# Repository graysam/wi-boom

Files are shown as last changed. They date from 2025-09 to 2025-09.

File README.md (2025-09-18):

# HV Trigger Async (ESP32 / ESP32-S3)

Firmware for ESP32 boards hosting a minimal web UI to safely arm and trigger a high‑voltage initiator. AsyncTCP + ESPAsyncWebServer power a WebSocket control channel; configuration persists via Preferences.

## Features
- SoftAP: `Trigger-Remote` / `lollipop`, IP `10.11.12.1`.
- Inline UI from PROGMEM; no filesystem required.
- WebSocket at `/ws` for telemetry (~250 ms) and commands.
- Pulse controls: mode `single` or `buzz`, width, spacing, repeat.
- Hardware LEDs: amber/green (network/WS), red (armed), blue (pulse).
- Status bar: WS and Armed LEDs, mode label (BUZZ/SINGLE‑SHOT), compact `W/S/R` values (e.g., `31/38/3`), AP name; reconnect overlay while WS is down.
- OTA via ArduinoOTA (TCP/3232) — update while the app is running.
- Verbose Serial logs for boot, prefs, HTTP, WS, and actions.

## Quickstart
1. Dependencies: ESP32 core (recommended 2.0.14), libraries in `library-notes.txt`.
2. Build & Burn scripts (recommended):
   - Windows: `buildAndBurn.ps1` (or `buildAndBurn.bat` wrapper)
   - macOS/Linux: `chmod +x buildAndBurn.sh && ./buildAndBurn.sh`
   Scripts prompt for sketch, FQBN, clean, port selection, upload, and can open a serial monitor.
3. Manual (Arduino IDE):
   - ESP32 Dev Module (ESP32‑WROOM‑32): select Board "ESP32 Dev Module".
   - ESP32‑S3 Dev Module: select Board "ESP32S3 Dev Module" and enable USB CDC on boot.
   Then open `hv_trigger_async.ino` and Upload.
4. Connect to AP `Trigger-Remote` and open `http://10.11.12.1/`.
5. OTA Update (optional):
   - Ensure your PC and the device are on the same network (AP or STA).
   - Arduino IDE: use the Network Port entry if available.
   - Arduino CLI: `arduino-cli upload -p 10.11.12.1:3232 --fqbn esp32:esp32:esp32 hv_trigger_async.ino` (replace FQBN for ESP32‑S3).

## Controls & Ranges
- Mode: `single` or `buzz`.
- Width: 5–100 ms; Spacing: 10–100 ms; Repeat: 1–4.
- Arm/Disarm gates firing; cfg changes are ignored while armed.

## Build & Tools
- Scripts: see above. CLI fallback in `README.build.md`.
- Serial monitor: `arduino-cli monitor -p COMX -c baudrate=115200`.
- WebSocket test (PowerShell): `powershell -ExecutionPolicy Bypass -File tools\\test_ws.ps1`

## API Reference
See `docs/WS_API.md` for WebSocket message formats, examples, and flows.

## Code Map
- `hv_trigger_async.ino`: setup/loop, telemetry tick, indicators.
- `web_server.cpp/.h`: AP setup, async server, WebSocket, inline UI, actions.
- `config.h`: pins, SoftAP settings, defaults; edit pins here if needed.

## Hardware
- KiCad project resides in `hardware_kicad/` (schematics `*.kicad_sch`, board `*.kicad_pcb`).
- Generated artifacts (plots, fabrication outputs, iBOM) are currently included from prototyping; going forward we’ll prefer attaching these to GitHub releases rather than committing bulk outputs.
- For fabrication, open in KiCad 7/8 and regenerate plots/GERBER/Drill files as needed. Additional notes may be present in `hardware_kicad/`.

## Safety
Change the default SoftAP password before field use. Treat the trigger output as live hardware — validate with a dummy load first.

## Release v1.21a
- Prototype hardware integrated and tested with the firmware.
- Repo/docs tidy-up; encoding fixes and clearer setup notes.
- Tag: `v1.21a` marks the working prototype snapshot.

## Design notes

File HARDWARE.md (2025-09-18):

# Hardware (KiCad)

## Overview
- Project directory: `hardware_kicad/`
- Core sources: schematics (`*.kicad_sch`), board (`*.kicad_pcb`), project file (`*.kicad_pro`).
- Auxiliary: iBOM config (`ibom.config.ini`), optional STL and notes.

Prototype hardware for the trigger has been validated against the v1.21a firmware.

## KiCad Version
- Designed/tested with KiCad 7/8. Re‑generate outputs with your installed version.

## Fabrication Outputs
To produce fabrication outputs (Gerbers/Drill/PDF):
- Open the project in KiCad.
- Plot layers as required by your fabricator (F.Cu/B.Cu, F.SilkS, F.Mask, Edge.Cuts, etc.).
- Generate drill files (PTH/NPTH) and drill maps as needed.
- Optionally export PDFs for documentation and assembly guides.

Note: historical “plotter outputs” and iBOM HTMLs may exist from prototyping. Future releases will attach curated artifacts to GitHub releases rather than committing bulk outputs.

## Safety Notes
- Treat the HV trigger output as live hardware — validate with dummy loads first.
- Verify pin mappings in `config.h` for your ESP32 variant before powering hardware.

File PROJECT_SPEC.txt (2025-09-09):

HV Trigger Async — Reproducible System Specification

1) Purpose & Scope
- Goal: A small, self‑hosted controller that safely “arms” and triggers a high‑voltage discharge device via a networked HTML UI or API.
- Constraints: Simple, robust, low‑latency; interlock system present at both front-end and on-mcu-backend tightly integrated with routine/s responsible for pulling fire GPIO high - never fire unless explicitly armed; persist user configuration across power cycles; provide Arduino-compatible OTA firmware update capability.
- Portability: This document defines behavior, protocols, and timing in platform‑agnostic terms so the system can be rebuilt in any language or on any MCU/SoC.

2) Hardware Abstraction (Platform‑agnostic)
- Outputs:
  - TRIGGER_OUT: digital output, active HIGH; drives HV trigger interface through appropriate isolation. Trigger is an N-channel mosfet drain-coupled via AC coupling LPF to pull the trigger pin of a 555 chip LOW upon fire command.
  - LED_READY_GREEN: ON when a control client is connected via WebSocket; otherwise used for network status (see Indicators).
  - LED_WAIT_AMBER: indicates Wi‑Fi wait/partial connectivity (see Indicators).
  - LED_PULSE_BLUE: indicates pulse activity (mirrors TRIGGER_OUT timing; may enforce minimum visible on & off‑time).
  - LED_ARMED_RED: slow blink whilst armed, NOT-mirrors BLUE LED during firing events.
- Optional Inputs: None required; an ADC may be reserved for future telemetry; treat as 0 if not available.
- Electrical: Debounce is not required on outputs. Ensure proper isolation for HV path. LEDs are present on pins as defined in pin_assignments.txt.

3) Operational Modes & Timing
- Fire modes:
  - single: Output a single HIGH pulse for width_ms.
  - buzz: Emit a buzz sequence per repetition: 10 sub‑pulses; each sub‑pulse is HIGH for width_ms then LOW; sub‑pulses are separated by spacing_ms; repetitions are separated by repeat_interval_ms.
- Parameters (runtime configurable, persisted):
  - width_ms: 5–100 (default 10)
  - spacing_ms: 10–100 (default 20)
  - repeat: 1–4 (default 1)
  - repeat_interval_ms: 50-1000 (default 150)
- Guard timing: If width_ms < 50, enforce an extra LOW delay to achieve at least 50 ms between successive HIGH operations (for visibility and power integrity).
- Telemetry tick: ~250 ms (configurable) for periodic state broadcast to be used both for logging by external processes and for telemetry feedback display and accurate interlock operation inside web UI.

4) Safety Model & State Machine
- States: DISARMED → ARMED → FIRING → DISARMED (auto after completion).
- Transitions:
  - DISARMED → ARMED: on Arm command; snapshot current configuration.
  - ARMED → FIRING: on Fire command; ignored if already FIRING.
  - FIRING → DISARMED: automatically upon completion (auto‑disarm) or on explicit Disarm by user via UI button.
- Rules:
  - Configuration changes (mode/width/spacing/repeat) are rejected while ARMED.
  - Fire is rejected unless ARMED and not FIRING.
  - All command results are reflected by the next telemetry frame. Should be confirmed as such by UI software else an error state is triggered and logged, prompting user to reinitialise or ignore.

5) Network Topology & Services
- Access Point (AP): Device hosts a Wi‑Fi SoftAP, default IPv4 10.11.12.1/24.
- Optional AP+STA: Device may also join a configured infrastructure SSID concurrently. Telemetry reports STA connectivity and IP when joined.
- HTTP service (port 80): Serves a minimal control UI (optional; API alone is sufficient).
- WebSocket (path /ws): Primary control channel for commands and telemetry.
- OTA (can be culled if storage/memory insufficient): Firmware update over network (default TCP port 3232). Requires an OTA‑capable partition layout on platforms that need it.

6) WebSocket Protocol (Canonical)
- Transport: WebSocket, text frames, JSON payloads, no newlines in frames.
- Telemetry (push ~250 ms and after commands):
  {
    "type": "state",
    "armed": false,
    "pulseActive": false,
    "pageCount": 0,                    // optional page load counter if UI served
    "wifiClients": 0,                   // connected AP stations
    "wifiConnected": false,             // true if any WS clients are connected
    "staConnected": false,              // AP+STA only
    "staIP": "",                        // AP+STA only
    "adc": 0,                           // reserved, 0 if unused
    "cfg": { "mode": "single|buzz", "width": 10, "spacing": 20, "repeat": 1 }
  }
- Commands (client → device):
  1) Arm/Disarm: { "cmd": "arm", "on": true|false }
  2) Configure (ignored when armed): { "cmd": "cfg", "mode": "single|buzz", "width": 5..100, "spacing": 10..100, "repeat": 1..4 }
  3) Fire (armed only): { "cmd": "fire" }
- Behavior:
  - After any valid command, device pushes a fresh telemetry frame.
  - Unknown fields are ignored but buffered and made available for logging via WS; unknown commands are no‑ops.

7) Indicators (Normative Behavior)
- Network/Ready LEDs:
  - If >=1 WS client connected: LED_READY_GREEN = ON (steady), LED_WAIT_AMBER = OFF.
  - Else if AP station count == 0: LED_WAIT_AMBER = slow blink (500ms on, 300ms off) LED_READY_GREEN = OFF.
  - Else (some AP stations, no WS): Alternate AMBER/GREEN to signal partial connectivity at a rate equivalent to a 200ms on-time for each colour.
- Armed LED:
  - ARMED: blink ~0.1 Hz; DISARMED: OFF. FIRING: alternates with Pulse LED; logical-NOT of Pulse LED during fire events.
- Pulse LED:
  - Mirrors TRIGGER_OUT HIGH while firing (both single and buzz sequences).

8) Persistence
- Store configuration (mode, width_ms, spacing_ms, repeat) in non‑volatile storage under a stable namespace.
- Load on boot before servicing network requests.
- Write through on configuration changes that are accepted (i.e., DISARMED only).

9) UI Requirements (Optional Reference Implementation)
- Client controls:
  - Mode: select [single|buzz] (radio)
  - Width: range 5..100 ms	(slider, 10ms increments)
  - Spacing: range 10..100 ms (slider, 5ms increments)
  - Repeat: range 1..4 (drop-down, default 1)
  - Arm: (gates firing)(somewhat less prominent than FIRE), coloured GREEN
  - Disarm: (similar prominence to ARM), clears ARMED state, re-enables controls, disables FIRE button
  - FIRE button: Prominent, central, defaults to disabled and visually reflects its enabled/disabled status. RED in colour when armed, light red when disarmed.
- Behavior:
  - While ARMED: sliders disabled; FIRE enabled.
  - While DISARMED: sliders enabled; FIRE disabled.
  - Bottom LCD-influenced “status bar”: AP stations, WS status, Armed state, Mode, Width, Spacing, Repeat.
  - enable FIRE immediately after sending Arm, remain consistent with telemetry.

10) Concurrency & Responsiveness
- The “fire” routine must not block request processing:
  - Run pulse generation in a separate task/thread/timer/ISR that leaves the event loop responsive.
  - Broadcast state during loop ticks; avoid pushing frames inside tight timing sections.
- Use message queues or atomic flags to communicate between network layer and timing layer.
- It is of high importance that the UI at the web interface remain in synchronisation with the current state of the incoming telemetry, which must itself only ever reflect the true state of the control routine, else error state is reported in status bar. include checks to ensure state and value consistency/lock in a holistic manner

11) OTA Update (Unless memory insufficient or CPU availability insufficient)
- Service an OTA agent on TCP port 3232 (or similar) concurrently with HTTP/WS.
- Platform‑specific: choose an OTA‑capable partition scheme (e.g., “default” A/B on ESP32) and ensure adequate free space.
- UX: report OTA start/progress/end and errors to the serial log.

12) Security & Safety
- Change default SoftAP password for field use.
- Treat TRIGGER_OUT as live hardware; test with a dummy load before connecting to HV.
- Consider adding a physical interlock/arming switch for extra safety.
- Limit exposure: run AP isolated; if enabling STA, restrict access (WPA2+ strong passphrase, VLANs, or IP allow‑lists).

13) Reference Timing (Pseudo‑logic)
- DISPATCH LOOP (every ~250 ms):
  - Push telemetry frame to all WS clients.
  - Update indicators (based on AP station count and WS client count).
  - Poll OTA handler (if present).
- FIRING (single):
  - TRIGGER_OUT = HIGH; LED_PULSE_BLUE = HIGH; delay width_ms
  - TRIGGER_OUT = LOW; LED_PULSE_BLUE = LOW
  - If width_ms < 50: ensure additional LOW delay to total ~50 ms
  - Auto‑disarm
- FIRING (buzz):
  - Repeat for r in 1..repeat:
    - For i in 1..10:
      - HIGH for width_ms, then LOW
      - If width_ms < 50: add extra LOW delay to reach ~50 ms
      - If i<10: delay spacing_ms
    - If r<repeat: delay spacing_ms
  - Auto‑disarm

14) Serial Logging (Recommended)
- Boot: libraries ready, pins configured, AP started (IP), STA join attempts and results.
- HTTP: route hits (e.g., GET /), client IPs.
- WebSocket: connect/disconnect events, message bodies received, JSON parse errors.
- Actions: CFG (with values), ARM on/off (with snapshot), FIRE start/completed.

15) Minimal “Any‑Language” Implementation Plan
- Step 1: Hardware Abstraction Layer (HAL)
  - Map TRIGGER_OUT and LED pins to target platform using pin_assignments.txt if present; implement digitalWrite/read and millisecond delays.
  - Provide a non‑blocking scheduler (event loop + periodic tick + worker task for firing).
- Step 2: Storage
  - Implement a small persistent KV store (mode, width, spacing, repeat); load on boot; write on accepted cfg updates.
- Step 3: Network
  - Bring up SoftAP (and optional STA) with a static IP (10.11.12.1/24 or platform equivalent).
  - Start HTTP (port 80) and WS (/ws) services. Serve a minimal HTML UI (optional).
- Step 4: Protocol & State
  - Implement WS message handling for arm/cfg/fire; enforce state machine rules.
  - Push telemetry frames on a fixed tick and after each command.
- Step 5: Fire Engine
  - Implement the timing routines for single and buzz modes with repeat and guard timing.
  - Ensure the engine runs independently of the network loop.
- Step 6: Indicators
  - Implement LED rules for network, armed, and pulse status.
- Step 7: OTA (optional)
  - Add OTA server (e.g., TCP/3232); ensure partitioning and concurrency with HTTP.
- Step 8: Test & Validate
  - Unit test the state machine; bench test timing with a logic analyzer; end‑to‑end WS tests.

16) Example Pin Mapping (Current ESP32‑CAM Build)
- TRIGGER_OUT = GPIO16 (active HIGH)
- LED_WAIT_AMBER = GPIO14
- LED_READY_GREEN = GPIO15
- LED_PULSE_BLUE = GPIO13
- LED_ARMED_RED = GPIO12
- SoftAP SSID = "Trigger-Remote", pass = "lollipop", IP = 10.11.12.1/24
- WebSocket path = /ws; HTTP = port 80; OTA = TCP 3232

17) Acceptance Criteria
- Disarmed by default on boot; configuration loaded and reflected in telemetry.
- Arm → Fire → Auto‑disarm cycle behaves exactly as specified for both modes and all parameter bounds.
- LED behavior matches rules for all connectivity and armed/firing states.
- Telemetry reflects reality (cfg, armed, pulseActive, Wi‑Fi/WS status) at ~250 ms cadence.
- Config updates while armed are rejected and do not alter the firing snapshot.
- OTA updates do not disrupt HTTP/WS when idle and complete with progress logs.

18) Extensibility Notes
- Multi‑channel outputs: replicate the Fire Engine with per‑channel configs; include channel id in WS messages.
- Authentication: add a shared token or per‑session pairing for WS commands.
 - Alternative transports: CoAP/UDP or BLE GATT with equivalent state and command semantics.

19) Board-Specific Pin Map (Added)
- ESP32 Dev Module (ESP32-WROOM-32)
  - TRIGGER_OUT = GPIO27 (active HIGH)
  - LED_WAIT_AMBER = GPIO26
  - LED_READY_GREEN = GPIO25
  - LED_PULSE_BLUE = GPIO33
  - LED_ARMED_RED = GPIO32
  - Pins are defined in config.h and may be adjusted per hardware.

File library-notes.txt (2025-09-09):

# =============================================================================
# file: library-notes.txt
# =============================================================================
# Required libraries (Arduino IDE > Library Manager):
#   - AsyncTCP by dvarrel / me-no-dev (ESP32)
#   - ESPAsyncWebServer by dvarrel / me-no-dev
#   - ArduinoJson by Benoit Blanchon
#
# ESP32 Boards package:
#   - "esp32" by Espressif (recommended 2.0.14 for current libs)
#
# Board selection:
#   - ESP32 Dev Module (ESP32‑WROOM‑32)
#   - ESP32S3 Dev Module (enable USB CDC; ensure correct PSRAM options for your module)
#
# Notes:
#   - UI is served from PROGMEM; no filesystem (LittleFS) required.
#   - SoftAP: SSID 'Trigger-Remote' / pass 'lollipop', IP 10.11.12.1/24 (see config.h).
#   - WebSocket at /ws pushes JSON telemetry ~every 250 ms and accepts:
#       {"cmd":"arm","on":true|false}
#       {"cmd":"cfg","mode":"single|buzz","width":ms,"spacing":ms,"repeat":1-4}
#       {"cmd":"fire"}
#   - Telemetry example:
#       {"type":"state","armed":false,
#        "cfg":{"mode":"single","width":10,"spacing":20,"repeat":1}}
#   - Fire is gated by 'armed'; PIN_PULSE_OUT goes HIGH for `width` ms.
#   - Buzz mode: 10 short pulses per repetition separated by `spacing` ms;
#     repetitions are separated by `spacing` ms.

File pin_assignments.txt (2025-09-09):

PIN ASSIGNMENTS

ESP32 Dev Module (ESP32‑WROOM‑32)
ORDER	GPIO#	COLOUR		PURPOSE
===================================================================
1			[Red Stripe]	Vcc
2					Ground
3	27				PULSE Signal (TRIGGER_OUT)
4					[Not Assigned]
5	26	ORANGE/AMBER	Wait; Wi‑Fi not connected
6	25	GREEN		Ready; Wi‑Fi Connected (WS client)
7	33	BLUE		Pulse signal active
8	32	RED		ARMED & Ready to fire
NO-MCU	N/A	GREEN		5V regulator active (power to MCU)

Legacy Mapping (ESP32‑CAM harness)
ORDER	GPIO#	NEW_GPIO	LED_COLOUR		PURPOSE
===================================================================
1				[Red Stripe]		Vcc
2							Ground
3	12	->16					PULSE Signal
4	11	->X(removed)				[Not Assigned] - Reserved for ADC-Input, no longer to be reserved.
5	16	->14		ORANGE_BICOLOUR		Wait; Wifi not connected
6	17	->15		GREEN_BIVOLOUR		Ready; Wi-Fi Connected
7	8	->13		BLUE			Pulse signal active
8	9	->12		RED			ARMED & Ready to fire
NO-MCU	N/A	n/a			GREEN			5V regulator active (power to MCU)

Notes
- Pins are defined in `config.h` and can be modified per hardware.
- ESP32‑S3 dev kits can use the legacy mapping above by default, or update `config.h` as needed.

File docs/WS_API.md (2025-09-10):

# WebSocket API (ws://10.11.12.1/ws)

This device exposes a single WebSocket endpoint at `/ws`. Messages are newline-free JSON objects. There are no explicit acks; the device pushes a fresh `state` message after handling a command and on a periodic tick (~250 ms).

Conventions
- Numbers are integers (ms, counts). Unknown fields are ignored.
- While `armed=true`, config (`cfg`) changes are rejected.
- UI enables FIRE only when `armed=true`.

State Telemetry
Sent periodically and after commands:

```
{
  "type": "state",
  "armed": false,
  "pulseActive": false,
  "pageCount": 1,
  "wifiClients": 0,
  "wifiConnected": false,
  "wsCount": 0,
  "apSSID": "Trigger-Remote",
  "staConnected": false,
  "staIP": "",
  "adc": 0,
  "cfg": { "mode": "single", "width": 10, "spacing": 20, "repeat": 1 }
}
```

Commands
1) Arm/Disarm
```
{ "cmd": "arm", "on": true }
```

2) Configure (ignored when armed=true)
```
{ "cmd": "cfg", "mode": "single|buzz", "width": 5..100, "spacing": 10..100, "repeat": 1..4 }
```

3) Fire (only when armed=true and not already firing)
```
{ "cmd": "fire" }
```

Example Flows
- Configure while disarmed, then arm and fire:
  - send {"cmd":"cfg","mode":"buzz","width":12,"spacing":25,"repeat":2}
  - wait for state with updated cfg
  - send {"cmd":"arm","on":true}
  - wait for state armed=true, then send {"cmd":"fire"}

Testing Tools
- Windows PowerShell: `tools/test_ws.ps1`
- macOS/Linux: `npx wscat -c ws://10.11.12.1/ws`

Notes
- After firing completes, the device auto-disarms.
- `wifiConnected=true` means at least one WS client connected; the green LED is solid in this state.

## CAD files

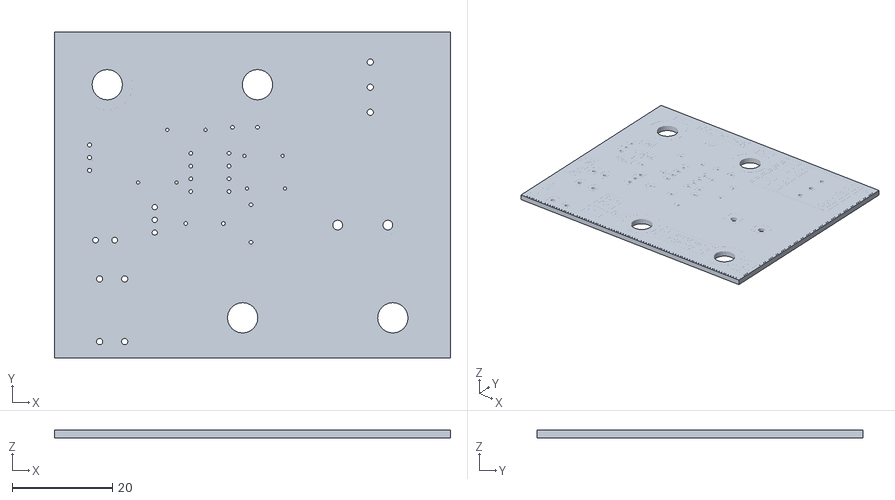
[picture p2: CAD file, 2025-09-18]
hardware_kicad/detonator trigger.stl
79.0 x 65.0 x 1.59

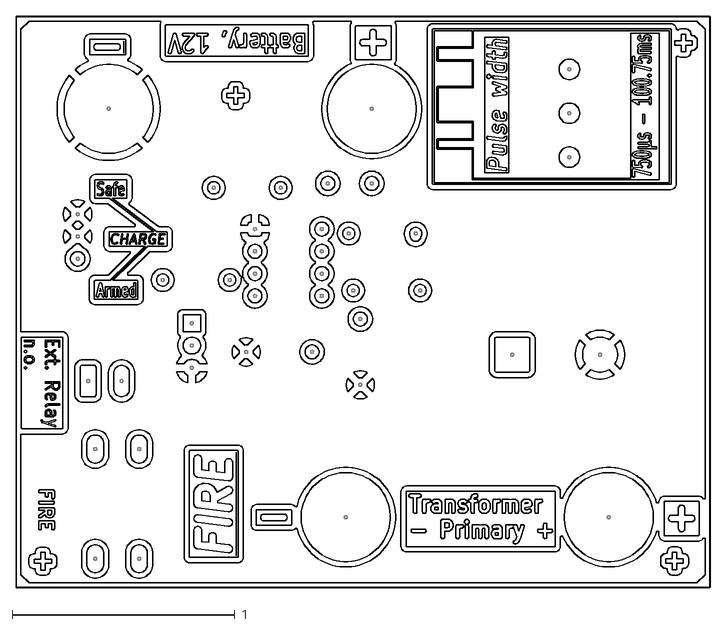
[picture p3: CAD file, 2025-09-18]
hardware_kicad/plotter outputs/R1.11/detonator trigger-F_Cu.dxf
3.11 x 2.56

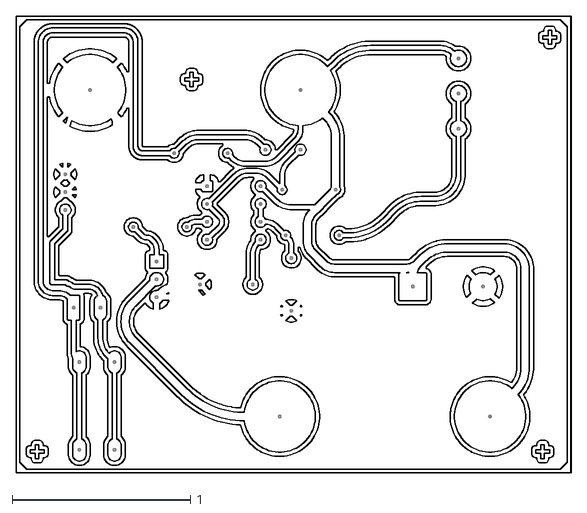
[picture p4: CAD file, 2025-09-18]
hardware_kicad/plotter outputs/R1.11/detonator trigger-B_Cu.dxf
3.11 x 2.56

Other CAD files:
hardware_kicad/plotter outputs/r1.11 dxf/detonator trigger-B_Cu.dxf
hardware_kicad/plotter outputs/r1.11 dxf/detonator trigger-F_Cu.dxf

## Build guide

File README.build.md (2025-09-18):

# Build / Flash Notes

Recommended Stack
- ESP32 core: 2.0.14 (stable with current Async libs). Newer 3.x cores may require updated ESP32Async libraries.
- Libraries: AsyncTCP, ESPAsyncWebServer, ArduinoJson (see `library-notes.txt`).

Scripts (preferred)
- Windows: `buildAndBurn.ps1` (or the `buildAndBurn.bat` wrapper)
- macOS/Linux: `chmod +x buildAndBurn.sh && ./buildAndBurn.sh`
  - Prompts for sketch, FQBN (default `esp32:esp32:esp32s3`), cleans build dir, compiles, lists ports for upload, retries once on errors, and can open a serial monitor.

Arduino IDE
- ESP32 Dev Module (ESP32‑WROOM‑32):
  - Tools > Board > ESP32 Arduino > ESP32 Dev Module
  - Open `hv_trigger_async.ino` and Upload.
- ESP32‑S3 Dev Module:
  - Tools > Board > ESP32 Arduino > ESP32S3 Dev Module
  - USB CDC On Boot: Enabled
  - Upload Mode: UART0 / Hardware CDC
  - Flash Size: per module (e.g., 8MB)
  - Open `hv_trigger_async.ino` and Upload.

Arduino CLI
- ESP32 Dev Module: `arduino-cli compile --fqbn esp32:esp32:esp32 hv_trigger_async.ino`
- ESP32‑S3 Dev Module: `arduino-cli compile --fqbn esp32:esp32:esp32s3 hv_trigger_async.ino`
- Upload (serial example): `arduino-cli upload -p COM9 --fqbn esp32:esp32:esp32 hv_trigger_async.ino`
- Upload (OTA example): `arduino-cli upload -p 10.11.12.1:3232 --fqbn esp32:esp32:esp32 hv_trigger_async.ino`
- Monitor: `arduino-cli monitor -p COM9 -c baudrate=115200`

Connect & Use
1. Join AP `Trigger-Remote` / pass `lollipop` (change in `config.h`).
2. Open `http://10.11.12.1/`. Use UI to set Mode/Width/Spacing/Repeat; Arm then FIRE.

Notes
- UI is served from PROGMEM; no filesystem needed.
- WebSocket at `/ws` sends telemetry ~every 250 ms and after commands. See `docs/WS_API.md`.
- OTA updates: device listens on TCP/3232; ensure your host and device share a network (AP or STA). In IDE, a Network Port may appear.

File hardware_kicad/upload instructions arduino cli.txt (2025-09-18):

    - Compile: arduino-cli compile --fqbn esp32:esp32:esp32s3:CDCOnBoot=cdc,USBMode=hwcdc,UploadMode=default .
      - Upload: arduino-cli upload -p COM9 --fqbn esp32:esp32:esp32s3:CDCOnBoot=cdc,USBMode=hwcdc,UploadMode=default
.
      - Monitor: arduino-cli monitor -p COM9 -c baudrate=115200

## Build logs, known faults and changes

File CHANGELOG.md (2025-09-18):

# Changelog

All notable changes to this project are documented here. Versions generally follow `MAJOR.MINOR.PATCH`.

## v1.21a — 2025-09-18
- Hardware: Initial KiCad project added; prototype hardware validated against firmware.
- Firmware: Stable async WebSocket control, telemetry, and pulse logic performing well in field tests.
- Docs: Cleanup for readability and encoding fixes; expanded build notes and hardware overview.
- Repo: Added broader `.gitignore`; removed accidental `node_modules` from tracking.

## v0.1.3
- fix(build): Windows PowerShell build script now uses `$PSScriptRoot` to resolve the script directory, avoiding a null `$MyInvocation.MyCommand.Path` inside functions.

## v0.1.2
- feat(ui): Status bar rework with WS/Armed LEDs, compact W/S/R values, and AP name.
- feat(ui): Auto‑reconnect WebSocket with overlay veil while disconnected.
- feat(ui): Live slider value boxes with units; Arm/Disarm buttons toggle visually.
- fix(ui): Content‑Security‑Policy allows inline script and ws/wss connect.
- feat: Add `tools/test_ws.ps1` WebSocket regression test (two‑client sync, arm/cfg/fire).
- docs: Update README, build notes, and WS_API with new fields (`apSSID`, `wsCount`) and OTA instructions.

## v0.1.1
- feat(esp32): Add ESP32 Dev Module (ESP32‑WROOM‑32) pin map; keep ESP32‑S3 compatibility.
- docs: Update build scripts and notes for both ESP32 and ESP32‑S3.
- fix(ui): Initial CSP header tweak to support inline UI.

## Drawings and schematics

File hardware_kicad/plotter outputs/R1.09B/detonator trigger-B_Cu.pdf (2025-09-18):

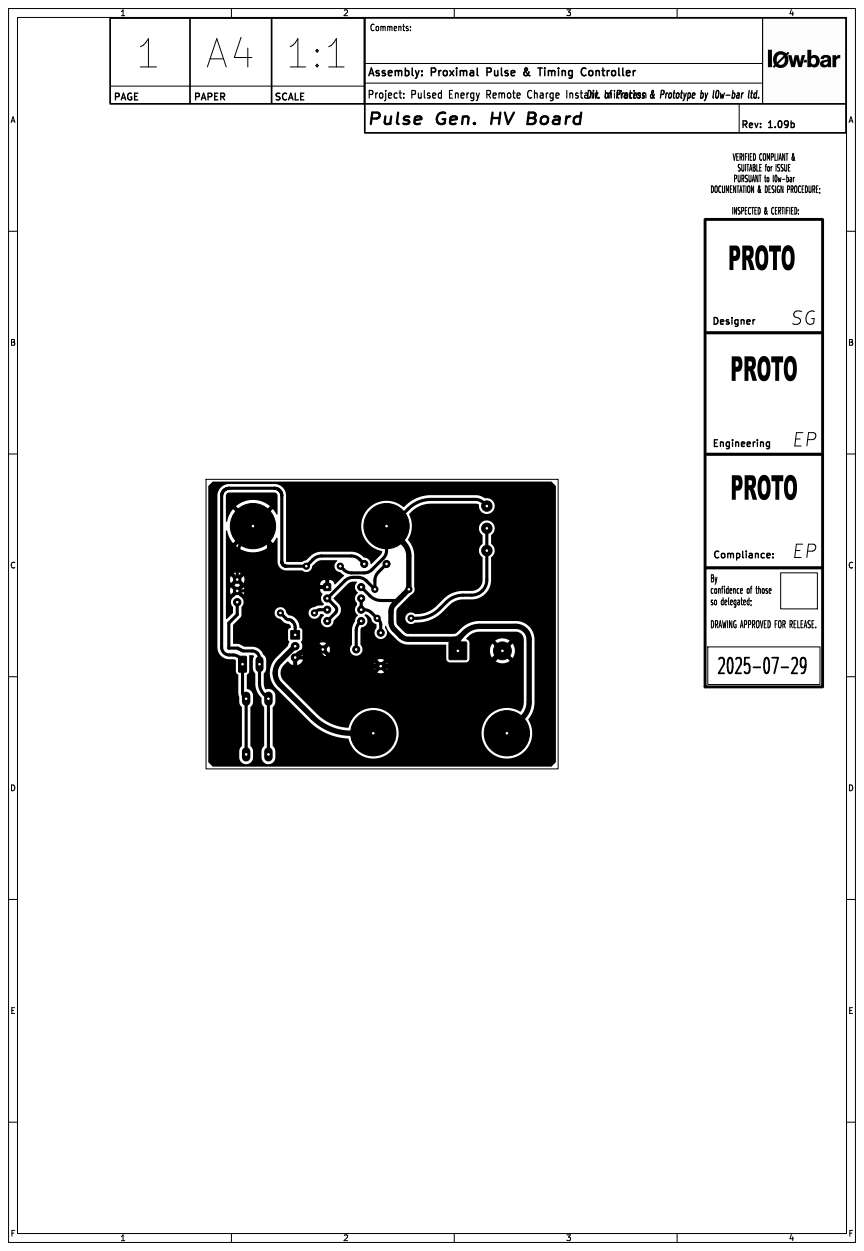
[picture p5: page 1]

Pulse Gen. HV Board

DRAWING APPROVED FOR RELEASE.

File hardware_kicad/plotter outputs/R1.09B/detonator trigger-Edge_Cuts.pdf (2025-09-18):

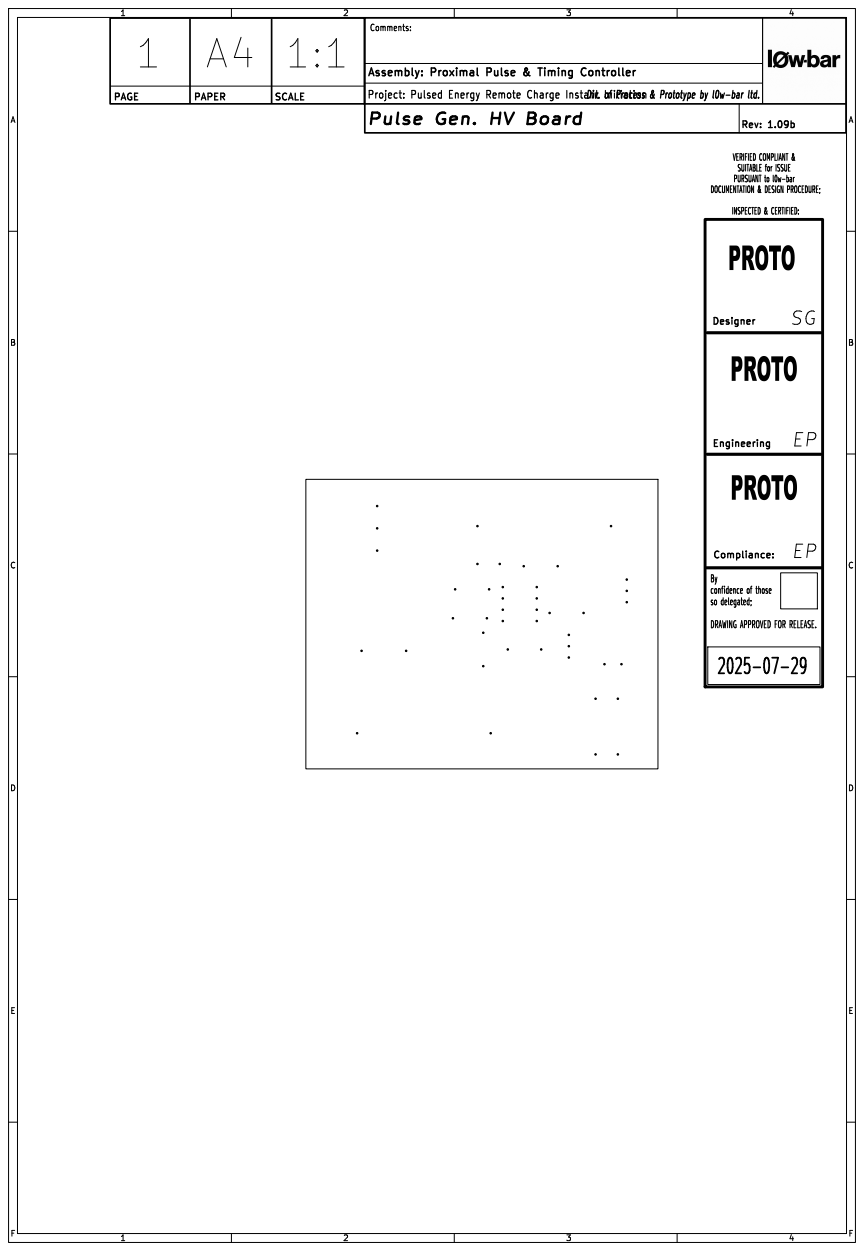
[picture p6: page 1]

Pulse Gen. HV Board

DRAWING APPROVED FOR RELEASE.

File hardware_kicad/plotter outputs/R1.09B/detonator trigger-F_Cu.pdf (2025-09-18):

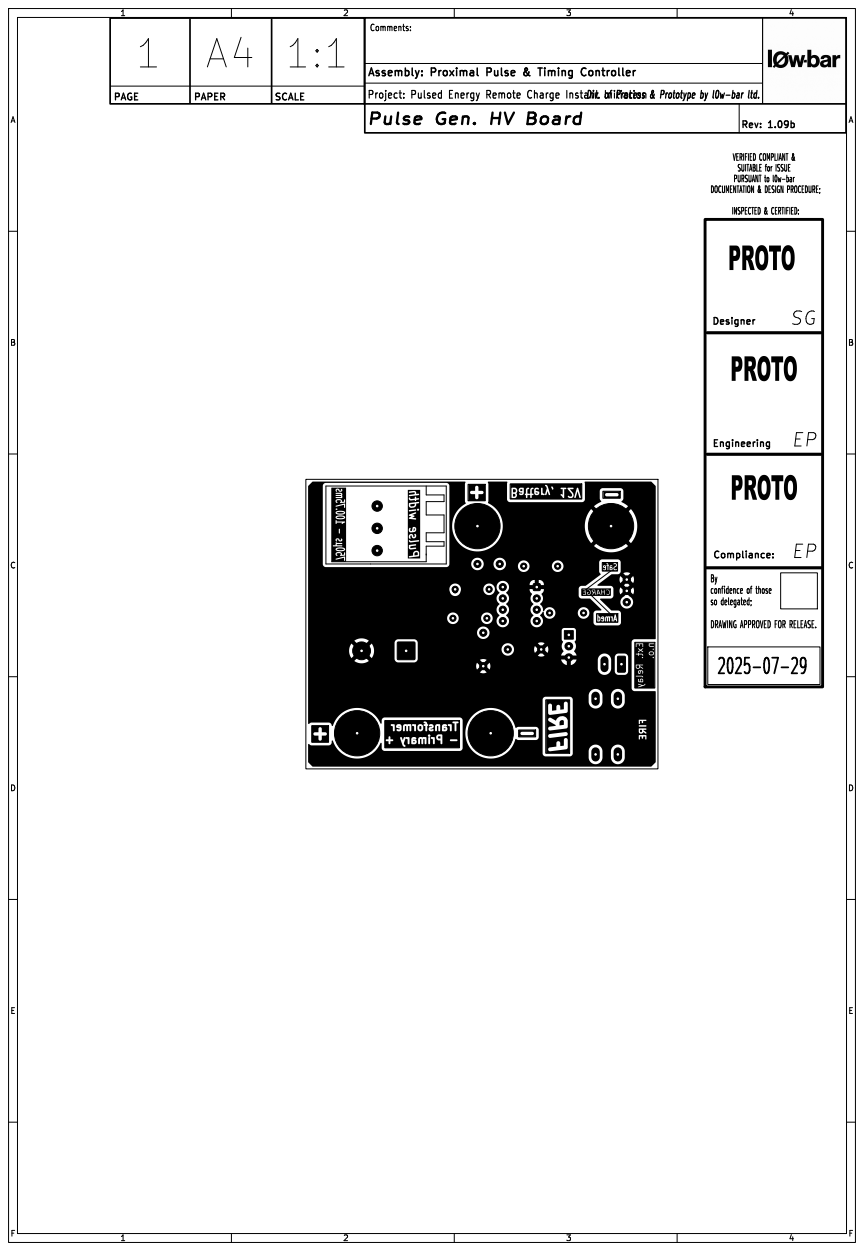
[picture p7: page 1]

Pulse Gen. HV Board

DRAWING APPROVED FOR RELEASE.

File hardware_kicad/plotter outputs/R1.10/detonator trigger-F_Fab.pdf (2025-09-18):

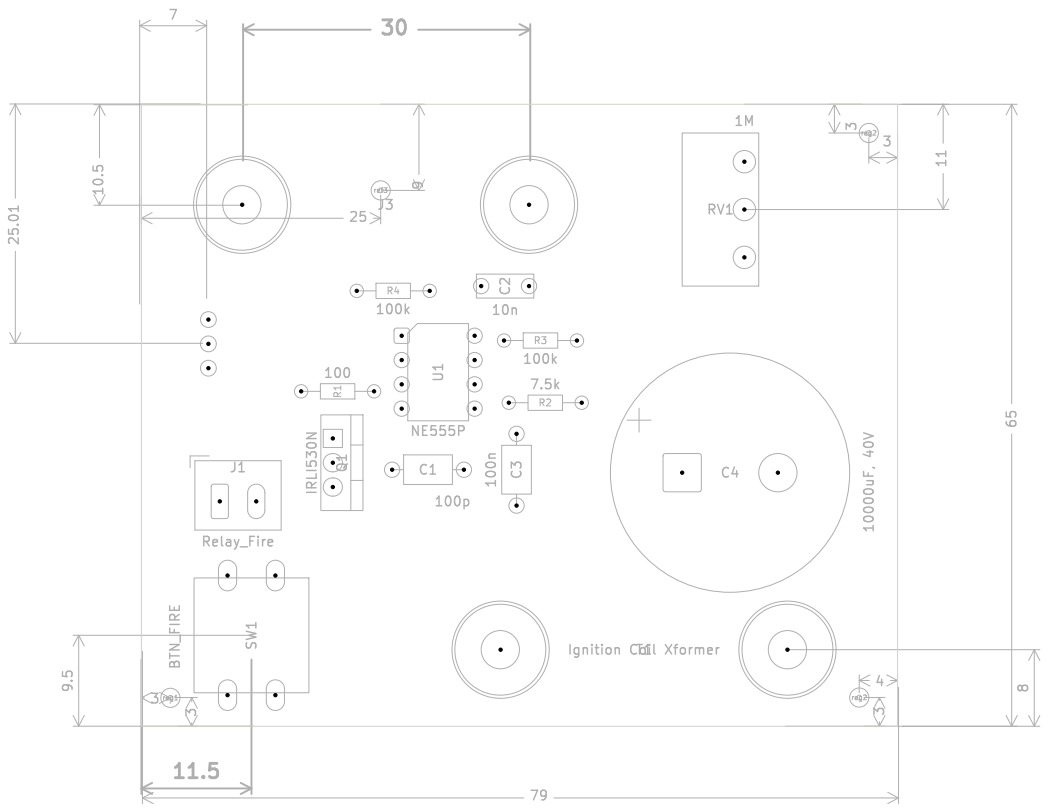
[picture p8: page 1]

Id: 2/2 Title: Pulse Gen. HV Board

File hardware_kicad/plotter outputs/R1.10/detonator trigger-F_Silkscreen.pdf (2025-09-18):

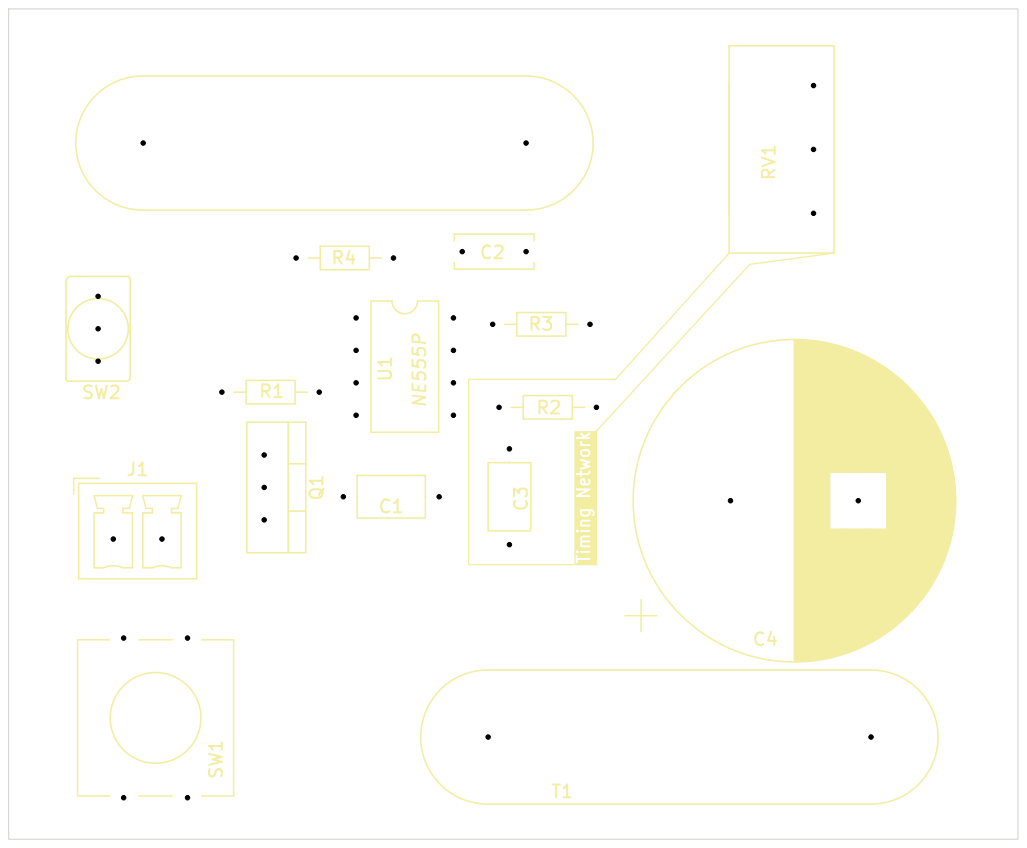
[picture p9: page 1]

Id: 1/2 Title: Pulse Gen. HV Board

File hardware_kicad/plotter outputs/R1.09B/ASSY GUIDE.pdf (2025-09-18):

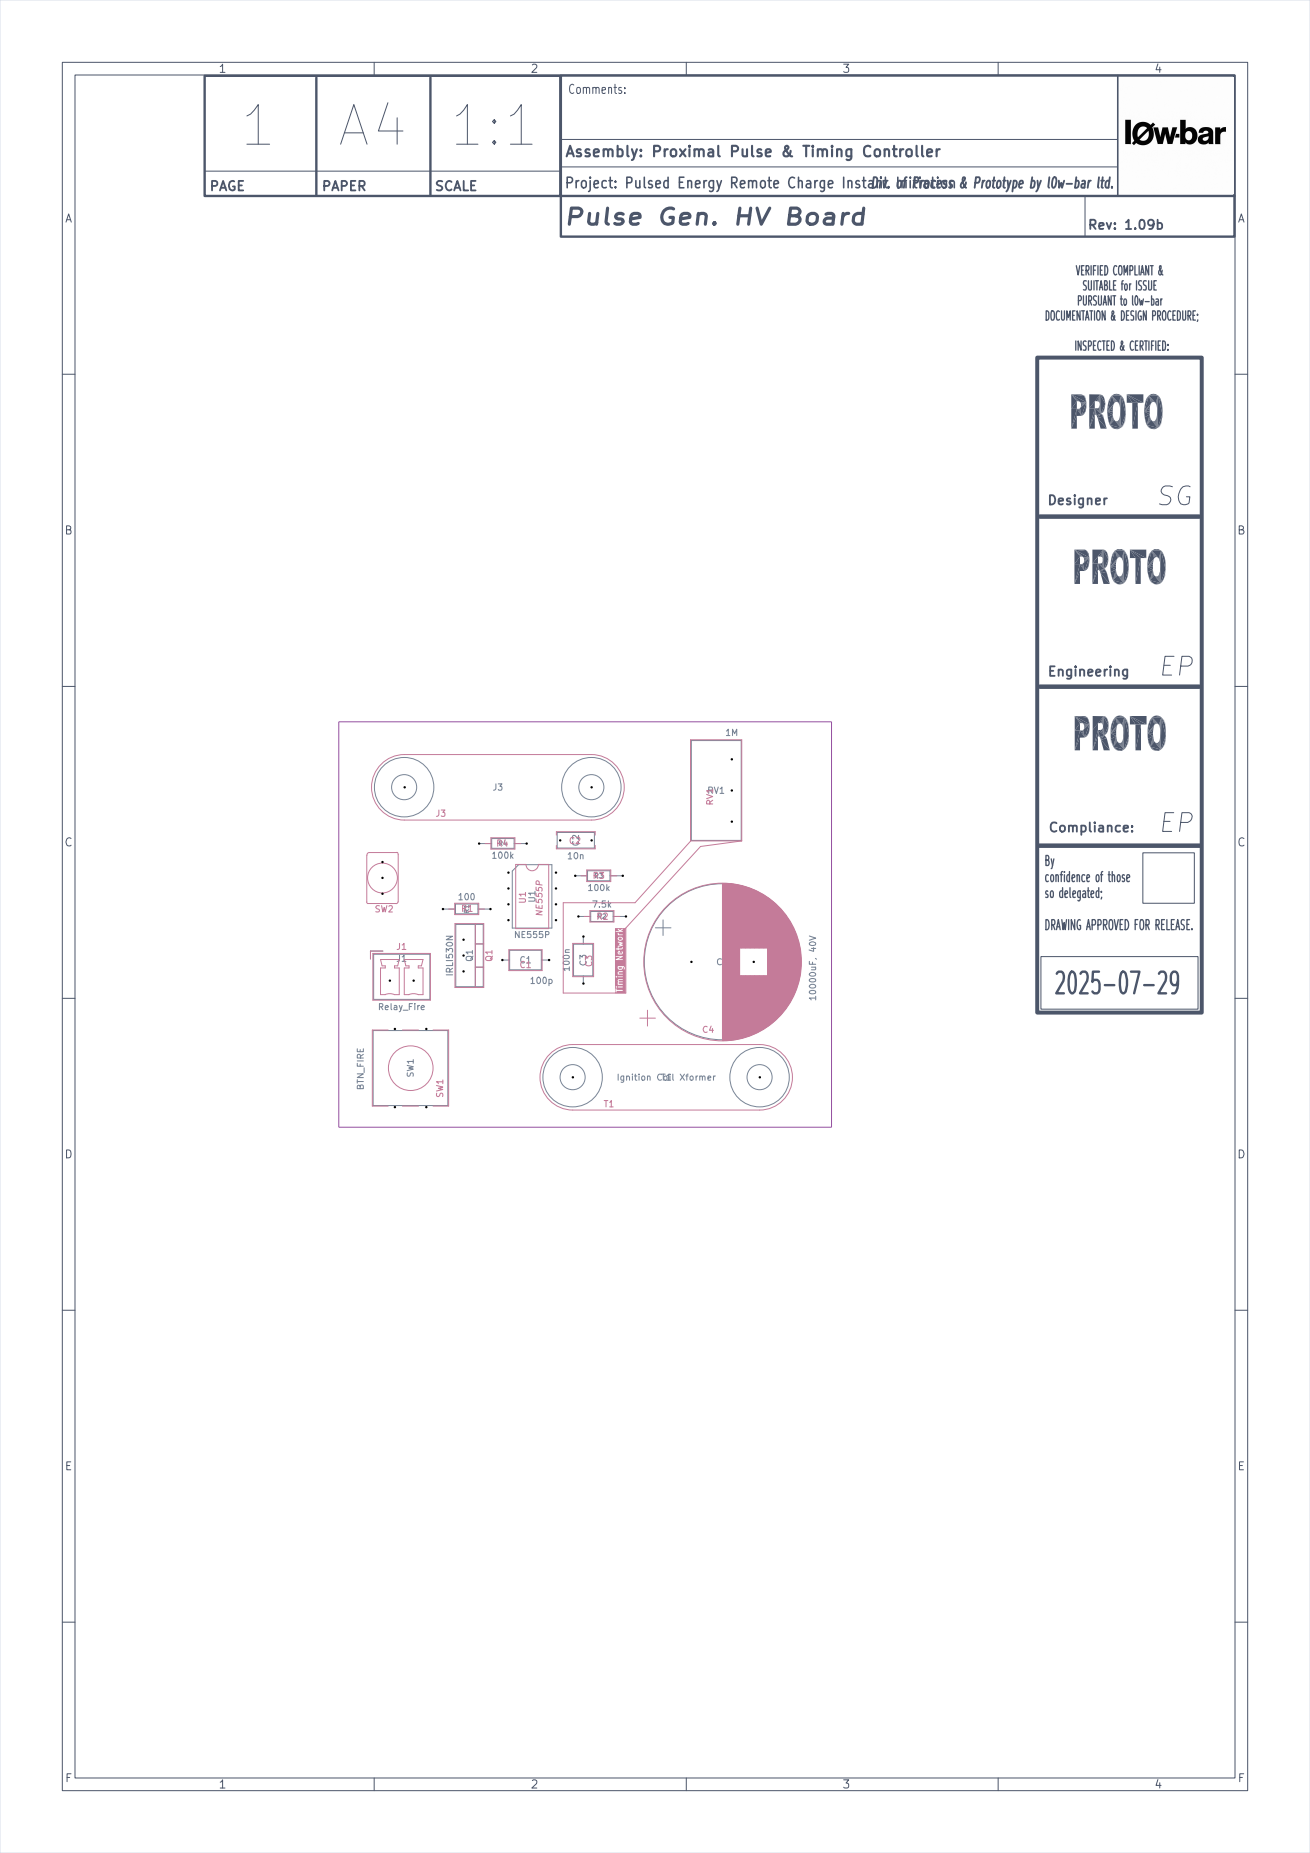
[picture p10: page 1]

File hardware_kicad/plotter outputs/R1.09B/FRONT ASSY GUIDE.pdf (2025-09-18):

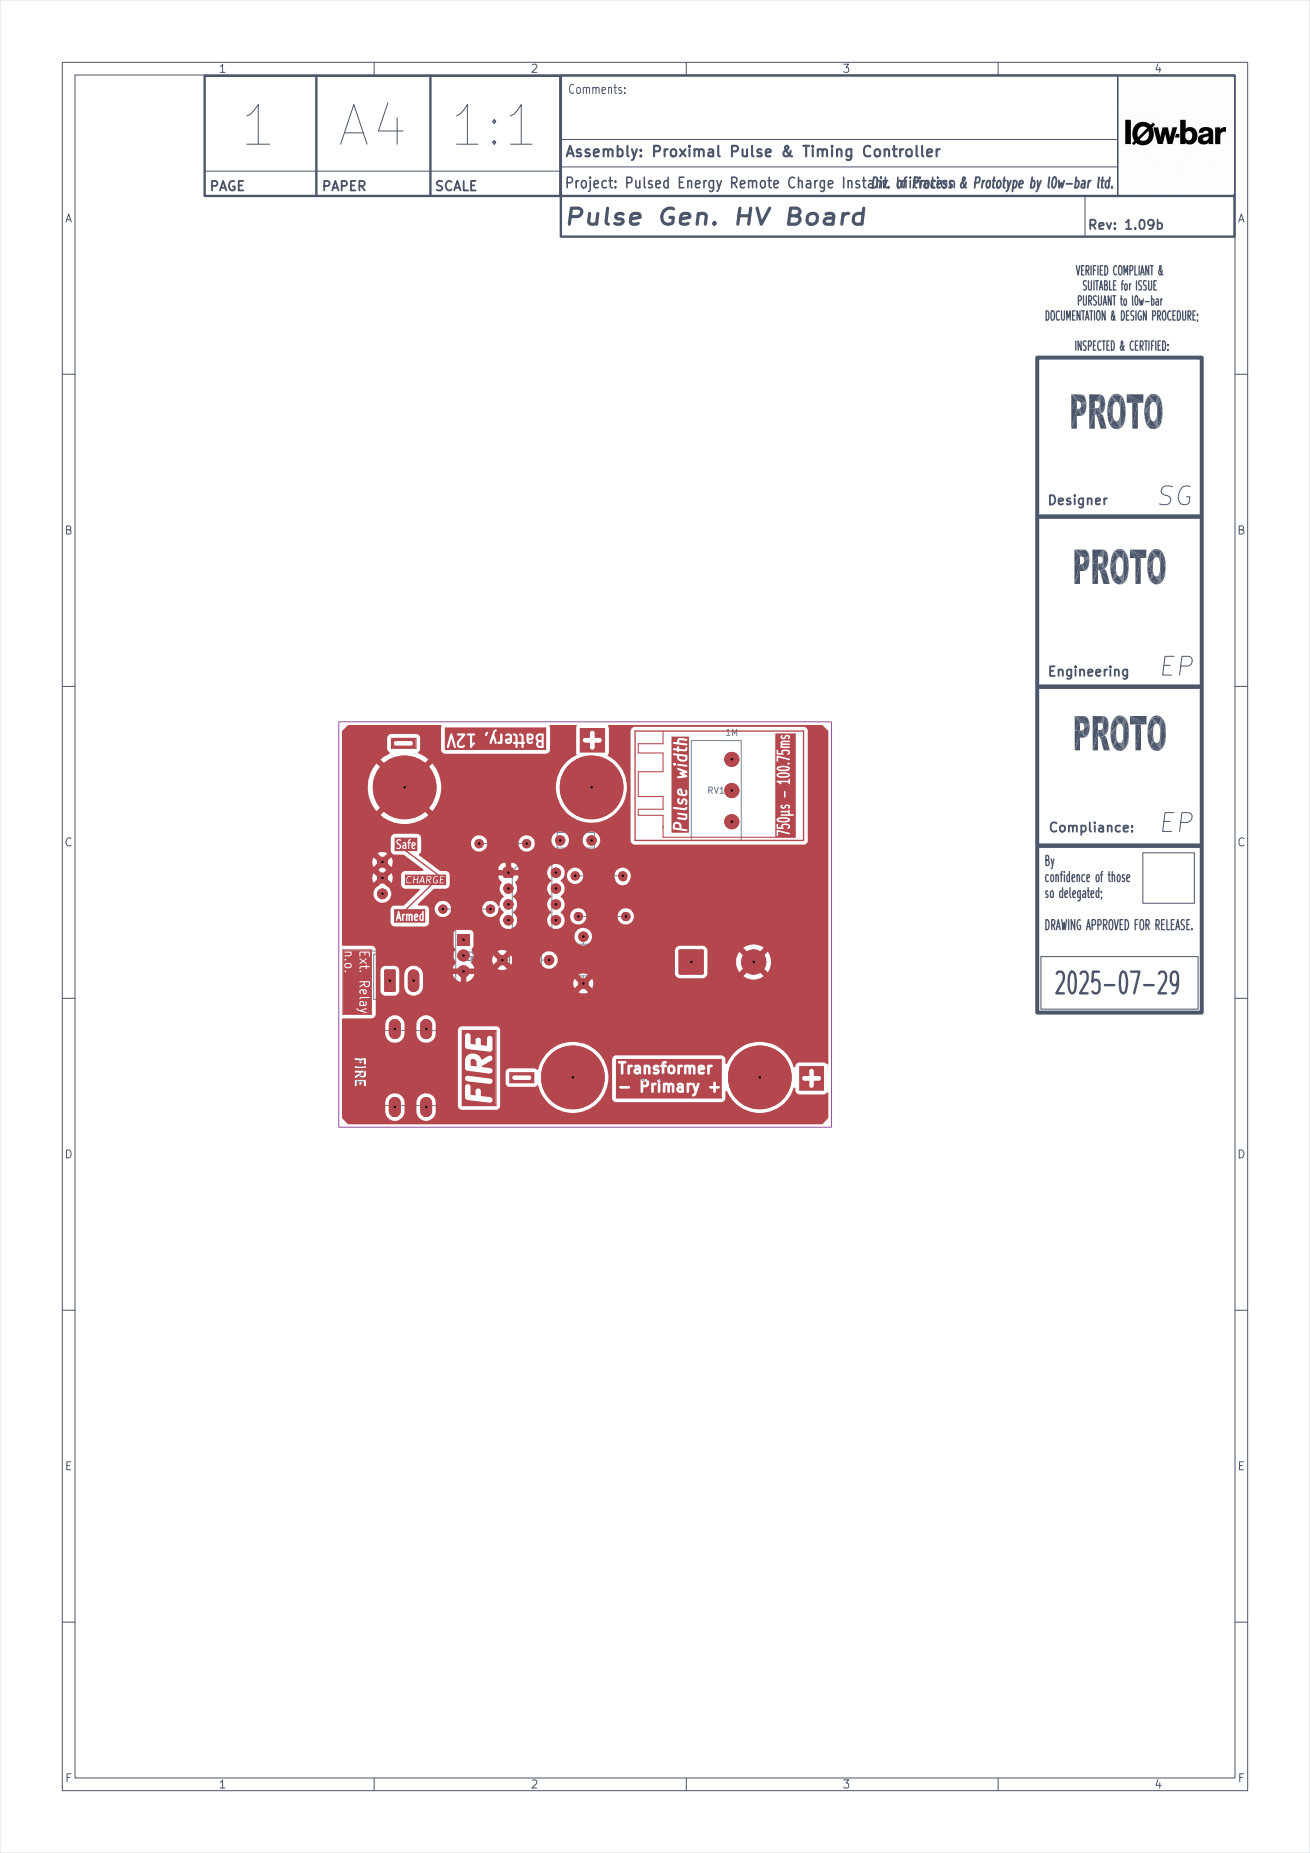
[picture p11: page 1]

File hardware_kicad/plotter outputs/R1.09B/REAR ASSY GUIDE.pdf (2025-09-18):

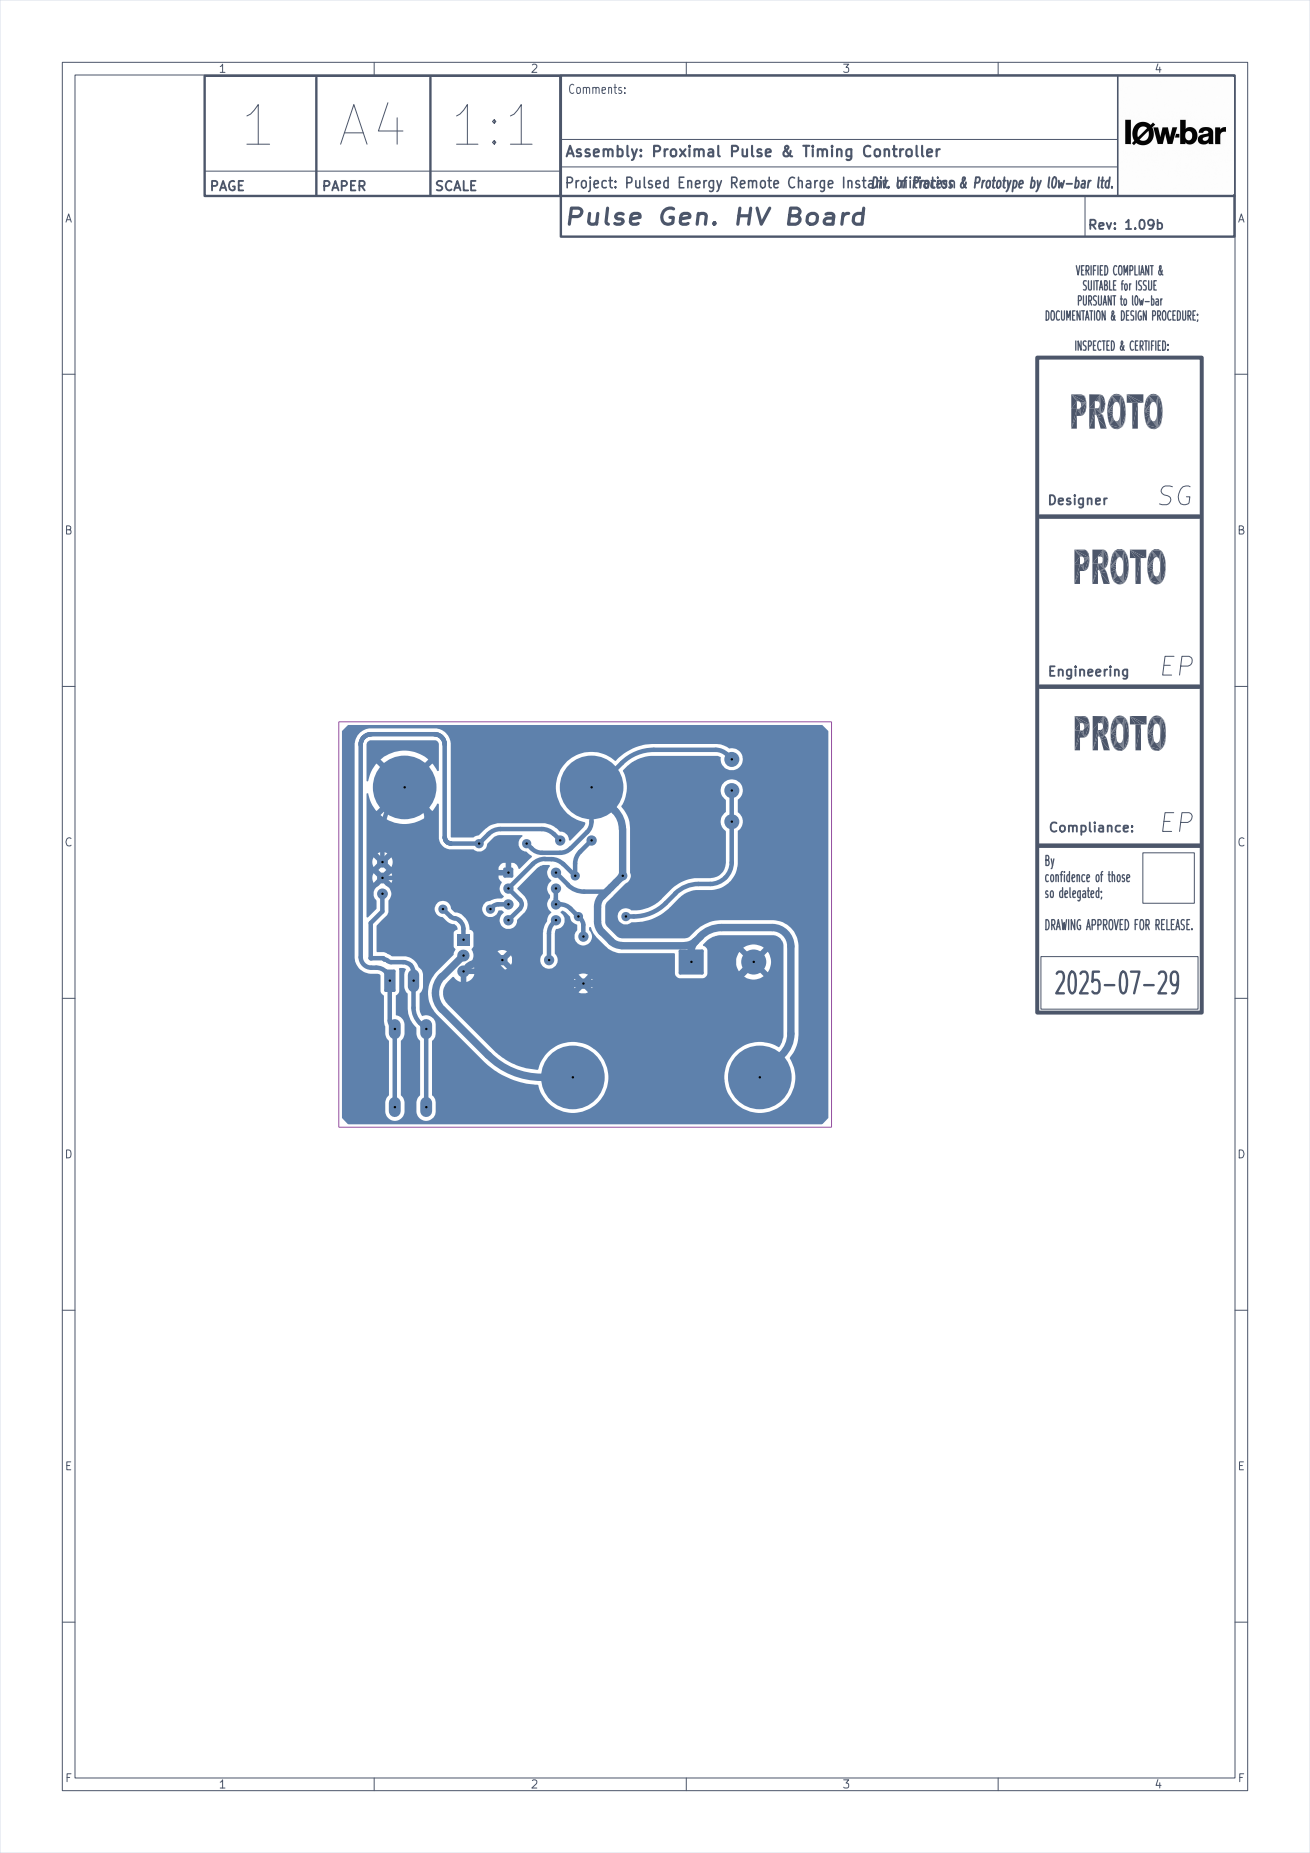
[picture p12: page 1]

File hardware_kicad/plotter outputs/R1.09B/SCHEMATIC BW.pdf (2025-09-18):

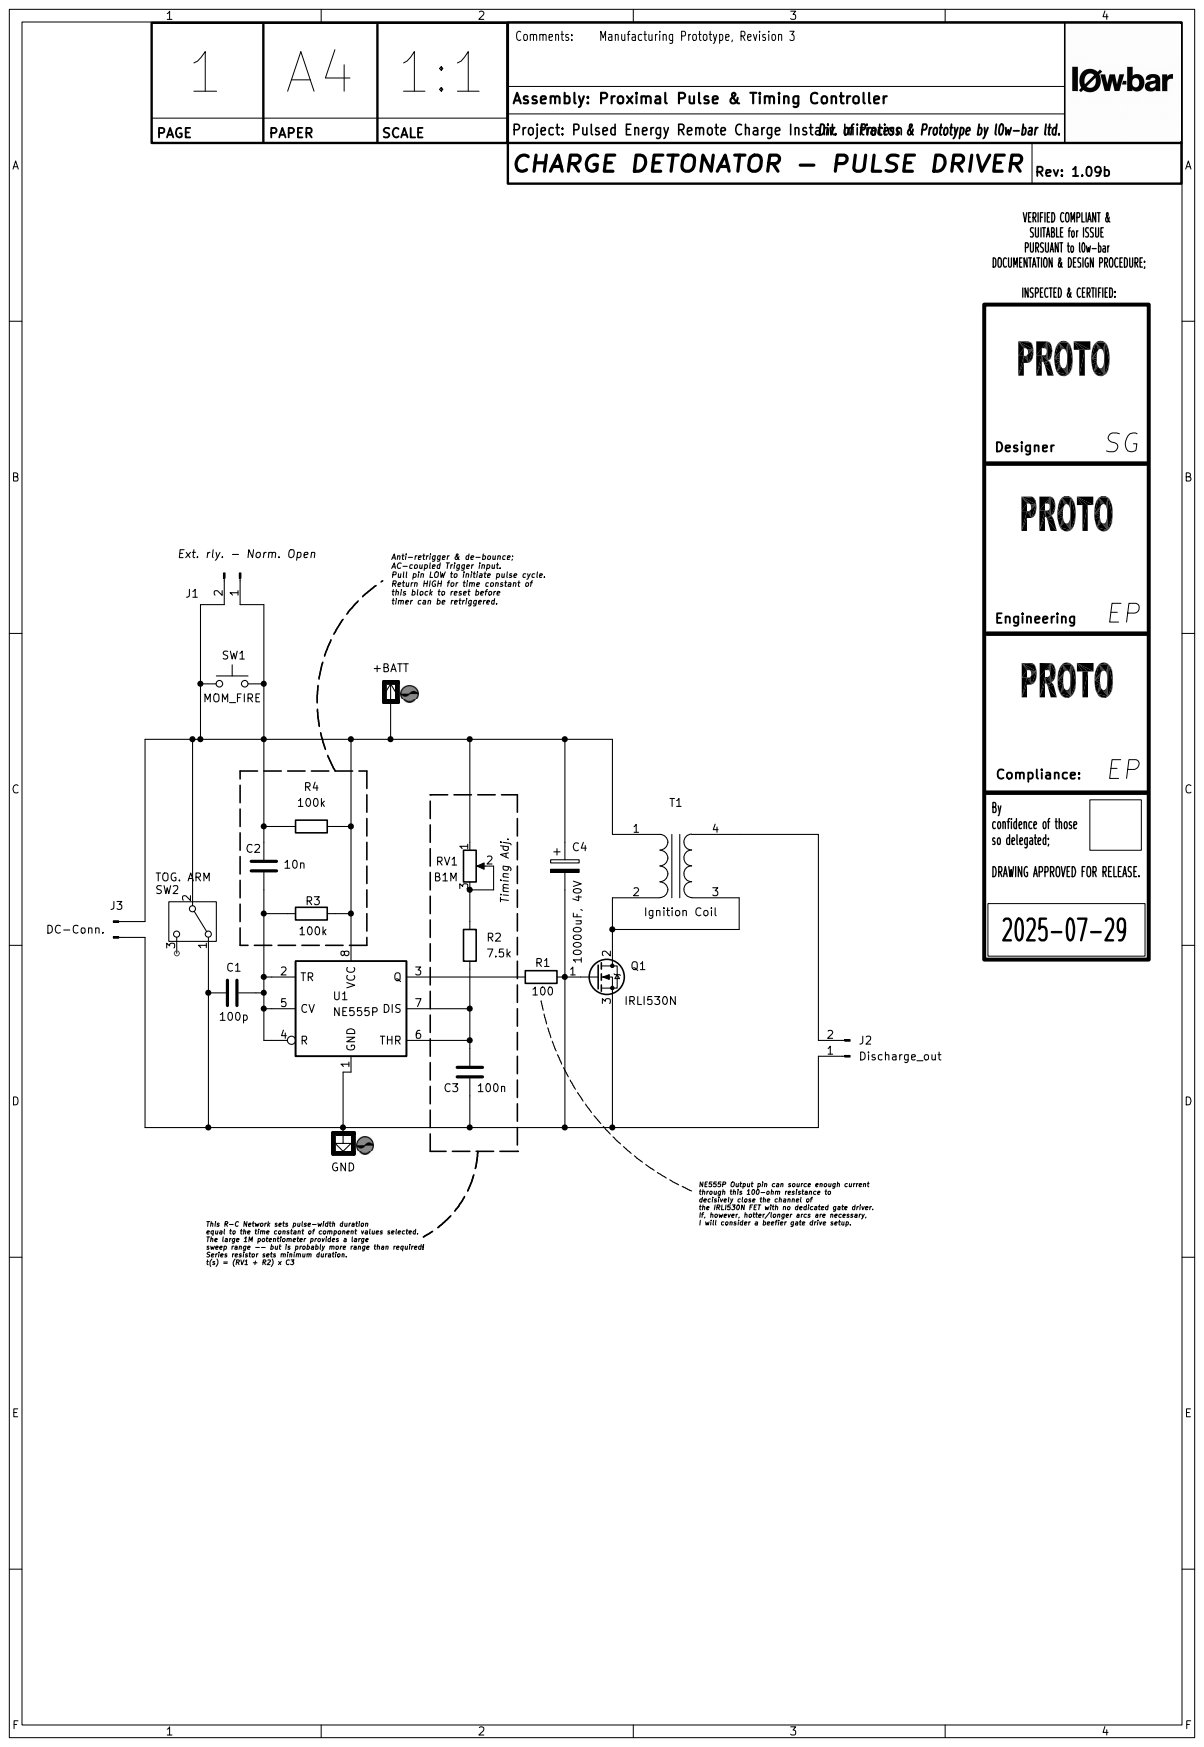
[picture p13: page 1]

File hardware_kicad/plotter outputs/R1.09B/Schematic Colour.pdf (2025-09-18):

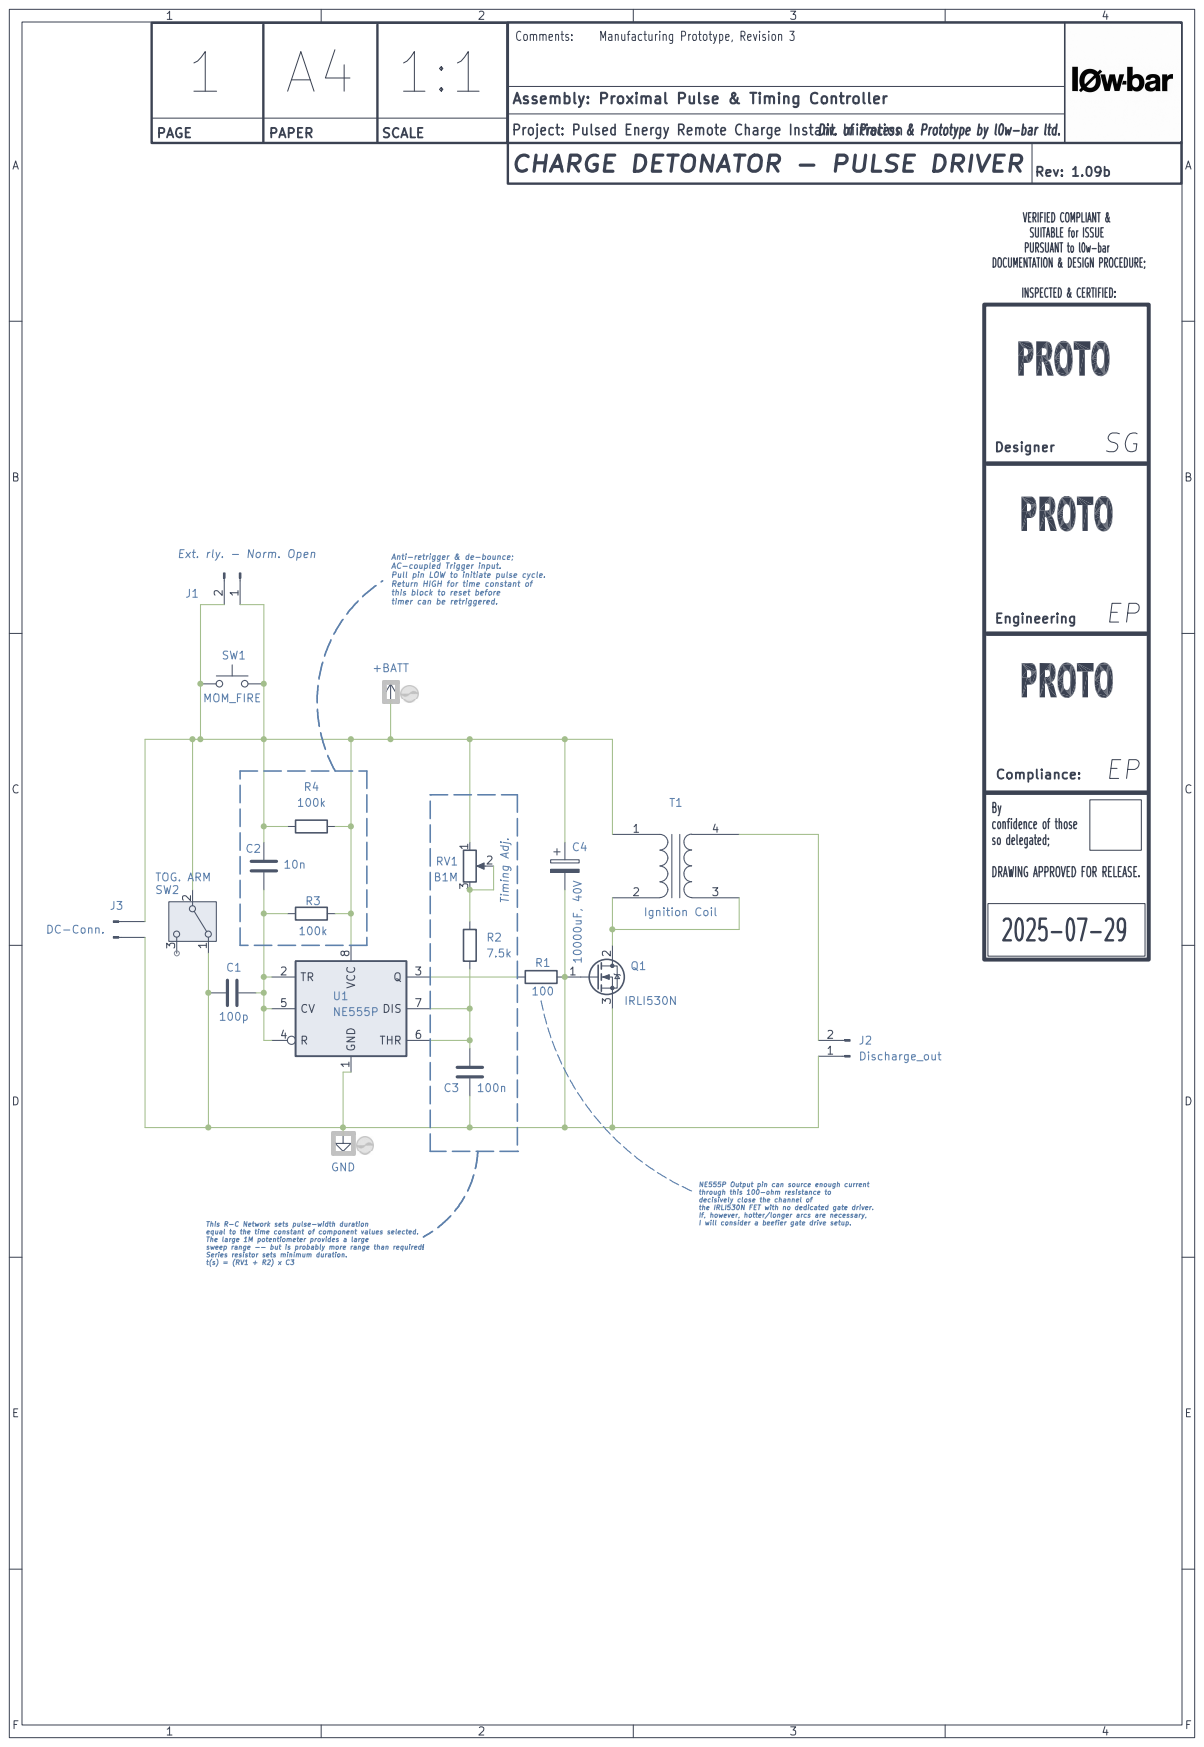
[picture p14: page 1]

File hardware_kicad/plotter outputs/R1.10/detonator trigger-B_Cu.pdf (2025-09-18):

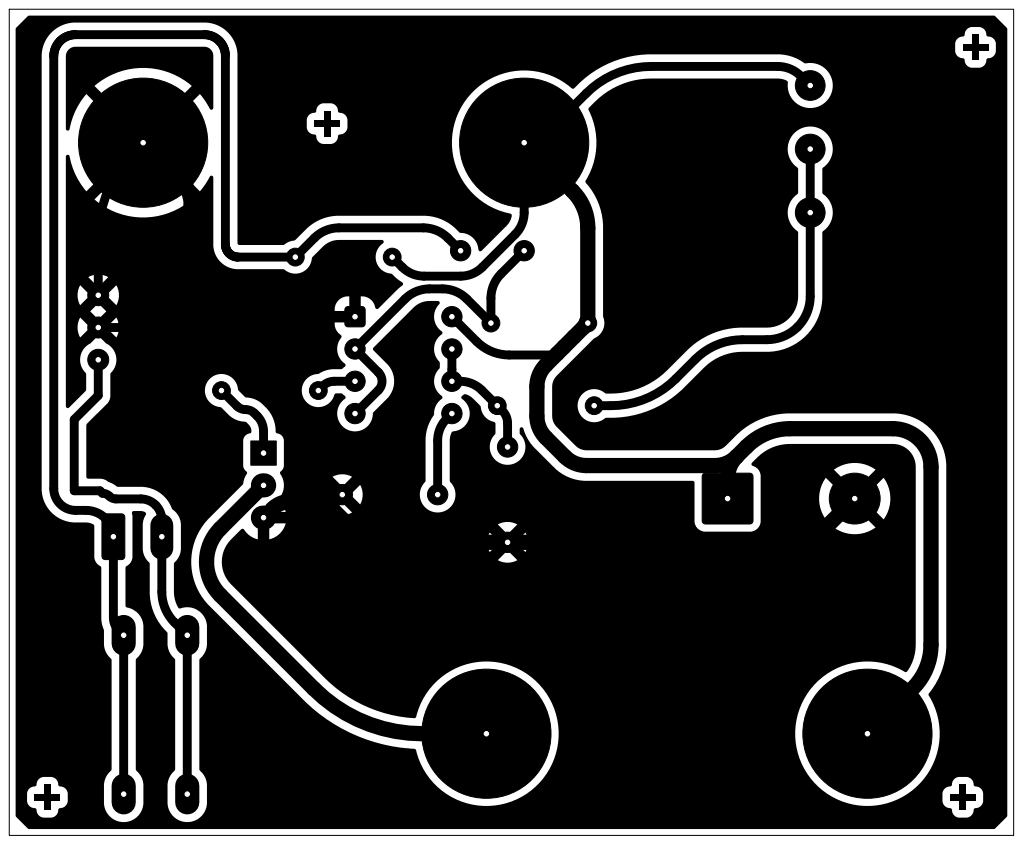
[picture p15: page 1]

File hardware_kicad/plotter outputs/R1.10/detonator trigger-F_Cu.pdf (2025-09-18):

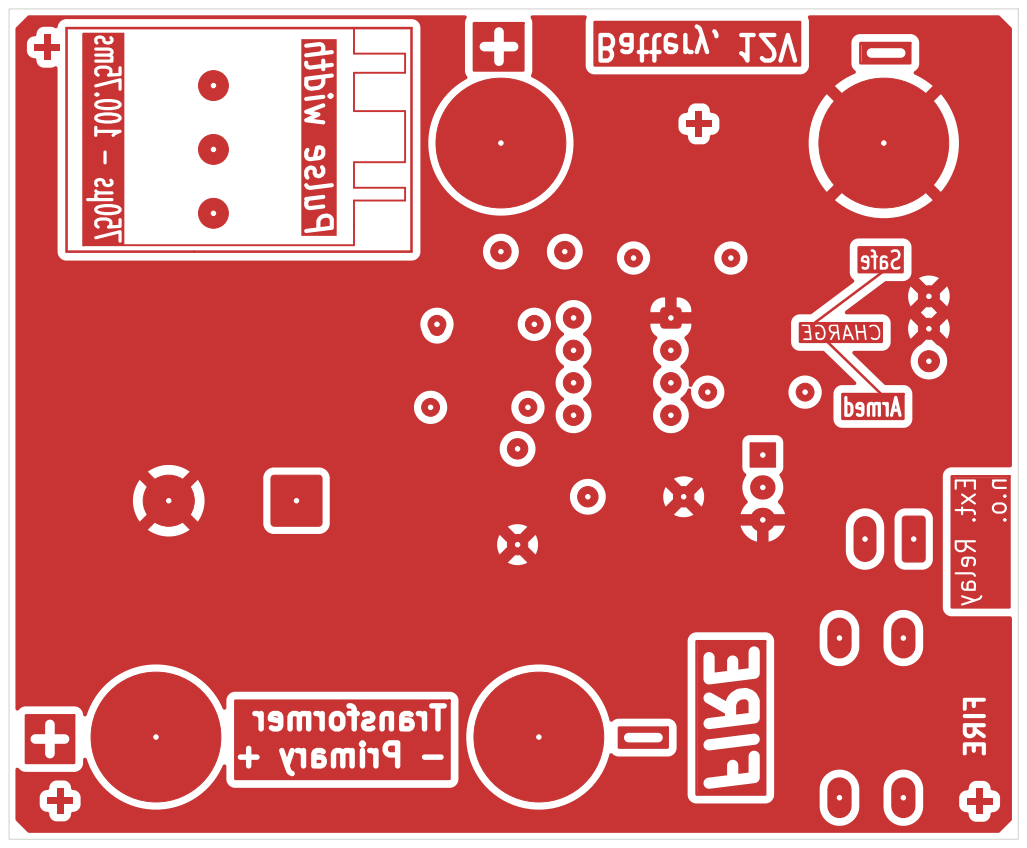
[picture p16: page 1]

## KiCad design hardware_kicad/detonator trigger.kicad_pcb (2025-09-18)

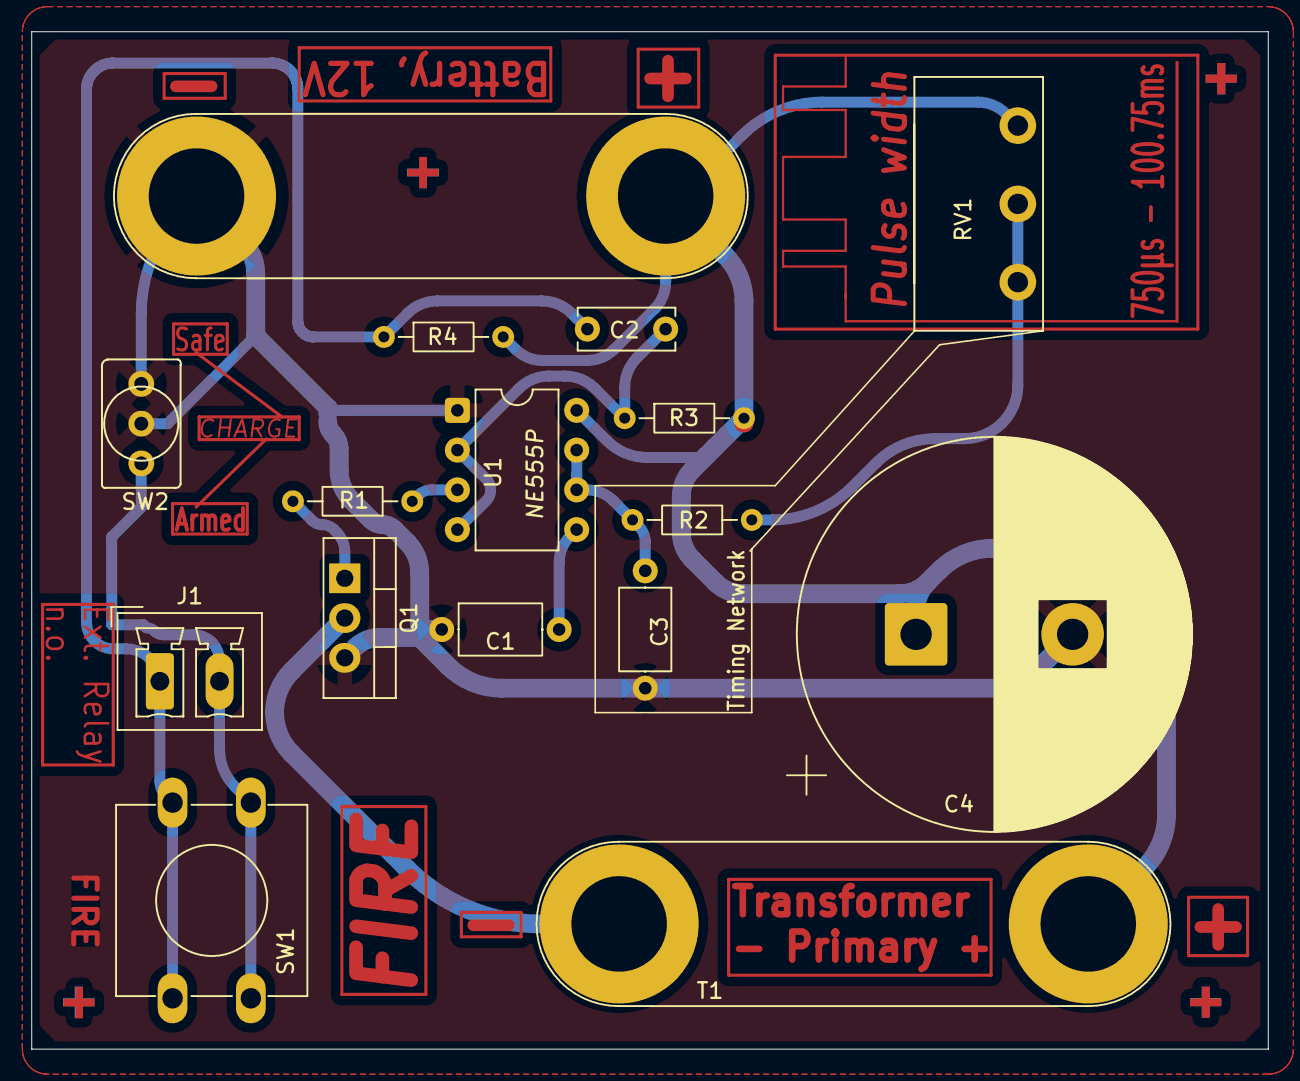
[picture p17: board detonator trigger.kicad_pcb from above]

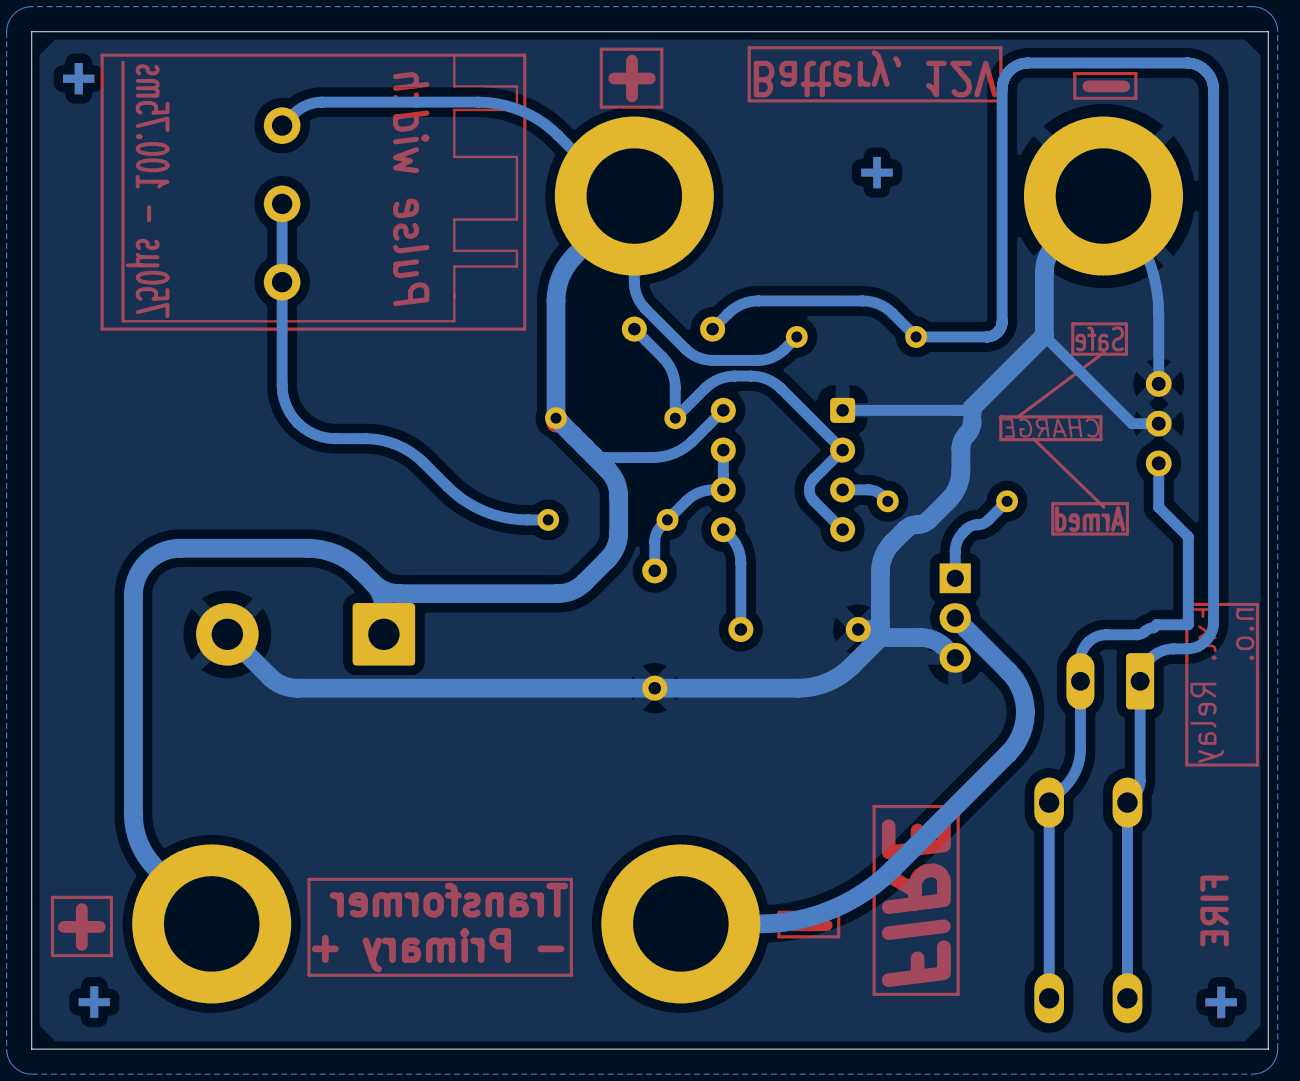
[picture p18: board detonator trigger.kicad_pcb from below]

Board: 2 copper layers, 79.0 x 65.0 mm, 24 parts (4 on the bottom side), 11 nets.

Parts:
C1: 100p; C_Axial_L5.1mm_D3.1mm_P7.50mm_Horizontal
C2: 10n; C_Disc_D6.0mm_W2.5mm_P5.00mm
C3: 100n; C_Axial_L5.1mm_D3.1mm_P7.50mm_Horizontal
C4: 10000uF, 40V; CP_Radial_D25.0mm_P10.00mm_SnapIn
J1: Relay_Fire; PhoenixContact_MCV_1,5_2-G-3.81_1x02_P3.81mm_Vertical
J3: + Battery (5-15V) -; Banana_Jack_2Pin
Q1: IRLI530N; TO-220-3_Vertical
R1: 100; R_Axial_DIN0204_L3.6mm_D1.6mm_P7.62mm_Horizontal
R2: 7.5k; R_Axial_DIN0204_L3.6mm_D1.6mm_P7.62mm_Horizontal
R3, R4: 100k; R_Axial_DIN0204_L3.6mm_D1.6mm_P7.62mm_Horizontal
RV1: 1M; Potentiometer_16mm-Alpha_Bourns_Omega-Single_Horizontal
SW1: BTN_FIRE; SW_PUSH-12mm
SW2: ARM; Switch_Toggle_SPDT_SubMini
T1: Ignition Coil Xformer; Banana_Jack_2Pin
U1: NE555P; DIP-8_W7.62mm
ref3, ref3#2: Fiducial_Cross_0.5mm_Mask2mm
reg1, reg1#2, reg2, reg2#2, reg2#3, reg2#4: Fiducial_Cross_0.5mm_Mask2mm

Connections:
+BATT: C4.1, J3.1, R3.2, R4.2, RV1.1, T1.1 (AA), U1.8 (VCC)
GND: C1.1, C3.2, C4.2, J3.2, Q1.3 (S), SW2.2 (B), SW2.3, U1.1 (GND)
unnamed: C2.1, J1.1, R4.1, SW1.2
unnamed: J1.2, SW1.1, SW2.1 (A)
unnamed: Q1.2 (D), T1.2 (AB)
unnamed: Q1.1 (G), R1.2
unnamed: R2.1, RV1.2, RV1.3
unnamed: C1.2, U1.5 (CV)
unnamed: C3.1, R2.2, U1.6 (THR), U1.7 (DIS)
unnamed: R1.1, U1.3 (Q)
unnamed: C2.2, R3.1, U1.2 (TR), U1.4 (R)

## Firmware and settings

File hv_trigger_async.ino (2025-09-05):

// ============================================================================
// file: hv_trigger_async.ino
// ESP32-S3 (Arduino) â€” Wi-Fi HV Trigger with Async Web UI and persistent config.
// ============================================================================

#include <Arduino.h>
#include "config.h"
#include "web_server.h"
#include <ArduinoOTA.h>

void setup() {
  Serial.begin(115200);
  delay(100);
  Serial.setDebugOutput(true);
  Serial.println(F("Boot: HV Trigger Async starting"));

  // GPIO init
  pinMode(PIN_PULSE_OUT, OUTPUT);
  digitalWrite(PIN_PULSE_OUT, LOW);

  pinMode(PIN_LED_AMBER, OUTPUT);
  pinMode(PIN_LED_GREEN, OUTPUT);
  pinMode(PIN_LED_PULSE, OUTPUT);
  pinMode(PIN_LED_ARMED, OUTPUT);
  Serial.println(F("GPIO: pins configured"));

  // ADC reserved pin removed on ESP32-CAM

  // Bring up AP/AP+STA + web stack
  setupWiFiAP();
  initWeb(); // mounts handlers + websocket + static page

  // OTA setup (TCP/3232)
  ArduinoOTA.onStart([](){ Serial.println(F("OTA: start")); });
  ArduinoOTA.onEnd([](){ Serial.println(F("OTA: end")); });
  ArduinoOTA.onProgress([](unsigned int p, unsigned int t){
    Serial.printf("OTA: %u%%\n", (p*100)/t);
  });
  ArduinoOTA.onError([](ota_error_t e){ Serial.printf("OTA: error %u\n", e); });
  ArduinoOTA.begin();

  Serial.println(F("System ready."));
}

void loop() {
  // Async server requires no busy loop; use millis for periodic state broadcast
  static uint32_t last = 0;
  const uint32_t now = millis();
  if (now - last >= TELEMETRY_PERIOD_MS) {
    last = now;
    broadcastState();  // push inputs/telemetry to any connected WS clients
  }
  updateIndicators();
  ArduinoOTA.handle();
}

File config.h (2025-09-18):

// file: config.h
// Shared configuration, pin map, and small helpers.
// ============================================================================

#pragma once
#include <Arduino.h>

// -------------------- Wi-Fi Mode --------------------
// When true, device runs in AP+STA mode and attempts to join STA_SSID/STA_PASS
// while also broadcasting its own SoftAP. When false, AP-only.
static constexpr bool WIFI_APSTA = false;
static constexpr char STA_SSID[] = "TimeBecomesALoop";     // set to join infrastructure Wi‑Fi (optional)
static constexpr char STA_PASS[] = "lollipop";

// -------------------- Pin Assignments --------------------
// Default mappings are chosen to be safe on the common dev kits.
// - For standard ESP32 Dev Module (ESP32-WROOM-32), use the provided GPIO set.
// - For ESP32-S3 (and other variants), use a conservative default compatible with prior builds.
// Pins are easily changed here as needed for your hardware.

#if defined(CONFIG_IDF_TARGET_ESP32)
// ESP32 Dev Module (ESP32-WROOM-32)

//  - PULSE Signal:        GPIO26
//  - AMBER (WiFi wait):   GPIO25
//  - GREEN (WiFi ready):  GPIO33
//  - BLUE (Pulse active): GPIO32
//  - RED (Armed):         GPIO27
static constexpr uint8_t PIN_PULSE_OUT   = 26; // HV trigger pulse output (active HIGH)
static constexpr uint8_t PIN_LED_AMBER   = 25; // AMBER = WiFi not connected
static constexpr uint8_t PIN_LED_GREEN   = 33; // GREEN = WiFi connected/ready
static constexpr uint8_t PIN_LED_PULSE   = 32; // BLUE = pulse active indicator
static constexpr uint8_t PIN_LED_ARMED   = 27; // RED  = armed & ready to fire

#else
// Fallback / prior mapping (ESP32-S3 dev kits and ESP32-CAM harness used previously)
//  - PULSE Signal:        GPIO16
//  - AMBER (WiFi wait):   GPIO14
//  - GREEN (WiFi ready):  GPIO15
//  - BLUE (Pulse active): GPIO13
//  - RED (Armed):         GPIO12
static constexpr uint8_t PIN_PULSE_OUT   = 16; // HV trigger pulse output (active HIGH)
static constexpr uint8_t PIN_LED_AMBER   = 14; // AMBER = WiFi not connected
static constexpr uint8_t PIN_LED_GREEN   = 15; // GREEN = WiFi connected/ready
static constexpr uint8_t PIN_LED_PULSE   = 13; // BLUE = pulse active indicator
static constexpr uint8_t PIN_LED_ARMED   = 12; // RED  = armed & ready to fire
#endif
// No ADC reserved in current mappings

// -------------------- Wi-Fi (SoftAP) --------------------
static constexpr char WIFI_AP_SSID[]     = "Trigger-Remote";
static constexpr char WIFI_AP_PASS[]     = "lollipop"; // change for field use

// SoftAP IPv4
static constexpr uint8_t AP_IP[4]        = {10,11,12,1};
static constexpr uint8_t AP_GW[4]        = {10,11,12,1};
static constexpr uint8_t AP_MASK[4]      = {255,255,255,0};

// -------------------- Behaviour --------------------
// Default timing values; runtime configurable and persisted via Preferences
static constexpr uint32_t DEFAULT_PULSE_WIDTH_MS = 10;   // single pulse width
static constexpr uint32_t DEFAULT_BUZZ_SPACING_MS = 20;  // inter-pulse gap for buzz mode
static constexpr uint8_t  DEFAULT_BUZZ_REPEAT    = 1;    // number of buzz repetitions
static constexpr uint32_t TELEMETRY_PERIOD_MS    = 250;  // State push interval

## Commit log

2025-09-03 Upload my starting point....
    Not good. but beginning to define the board, anyway.
2025-09-03 docs: refresh docs to match current codebase; add AGENTS.md contributor guide
2025-09-03 fix(web_server): remove stray trailing token causing compile error
    [web_server.cpp]
2025-09-03 test: add PowerShell WebSocket script to exercise arm/cfg/fire and observe telemetry
2025-09-03 feat(ui,led,debug): - add bottom status bar with live telemetry - optimistic arming in UI to enable FIRE; fix arm enabling bug - solid green LED when WS connected; cleanupClients for accuracy - add v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
    [hv_trigger_async.ino, web_server.cpp]
2025-09-03 chore(windows): switch to PowerShell build script; keep .bat as wrapper; improve FQBN handling and defaults
2025-09-05 Update README.md
    Addressed encoding conversion artefacts throughout text. replaced several ' â€“ '-like instances with the intended character. May have missed some.
2025-09-05 feat(esp32-cam): switch pin map, target & scripts - Update config.h pins per pin_assignments.txt (16,14,15,13,12) - Remove ADC reserved usage; keep telemetry shape - Set default FQBN to esp32:esp32:e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
    [config.h, hv_trigger_async.ino, web_server.cpp]
2025-09-05 feat(scripts,net,ota): - Add pre-action menus, scan sketches/builds, build/upload/combined modes - Port selection with busy-port retry; OTA upload option (network) - Default FQBN to esp32cam with OTA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
2025-09-09 feat(esp32): add ESP32 Dev Module pin map and update docs/build scripts; keep ESP32-S3 compatibility
2025-09-10 fix(ui,csp): allow inline script and ws/wss in CSP to restore WebSocket + controls on ESP32
    [web_server.cpp]
2025-09-10 feat(ui): resilient WS with auto-reconnect + veil; status LEDs; slider value boxes; compact status bar; show AP SSID; add wsCount/apSSID telemetry
2025-09-10 chore: ignore build/ artifacts; drop tracked esp32 build outputs
2025-09-10 fix(build): use to locate script dir in PowerShell; update CHANGELOG
2025-09-18 Major schematic revision
    Hardware schematics and PCB designs added, updated to revision 1.21a. Pin assignments changed.
    [ESP_ControlBoard.kicad_sch, detonator trigger - New Stackup.kicad_pcb, detonator trigger-B_Cu.dxf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]
2025-09-18 Tidying kicad folder for Git version tracking
    Removed extraneous files, ignore kicad_backups, ibom now included under version folder, though should remove all accumulated version trees in future commit
    [detonator trigger - New Stackup.kicad_pcb, detonator trigger.csv, detonator trigger_V2_With MCU_Trigger.kicad_sch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]
2025-09-18 chore(repo): tidy docs and ignores; drop node_modules and backups from tracking
    - Add HARDWARE.md and expand README
    - Fix encoding issues across docs
    - Expand .gitignore for KiCad outputs and node_modules
    - Remove tracked node_modules and KiCad backup zips
